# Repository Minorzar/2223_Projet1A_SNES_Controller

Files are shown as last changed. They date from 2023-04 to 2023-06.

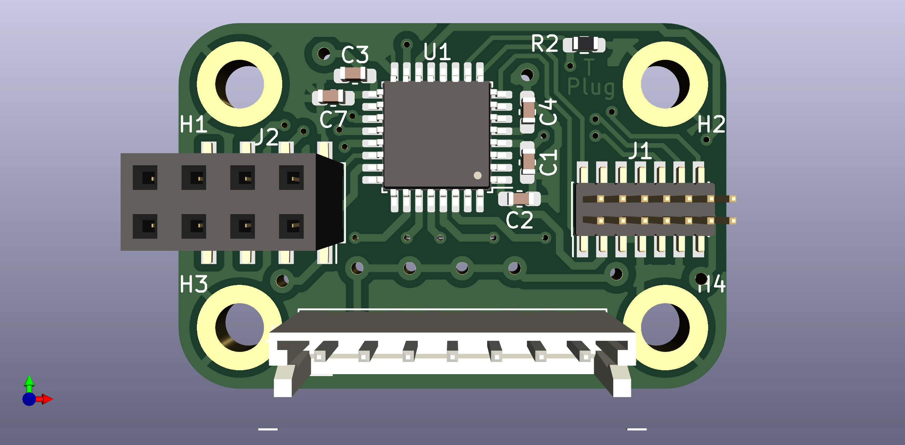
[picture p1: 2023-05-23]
Project_controller/Hardware/Kicad/# Image/Routing_V3_0_d/Plug_NRF24L01_Exclude_V3-3_3D_Top.png

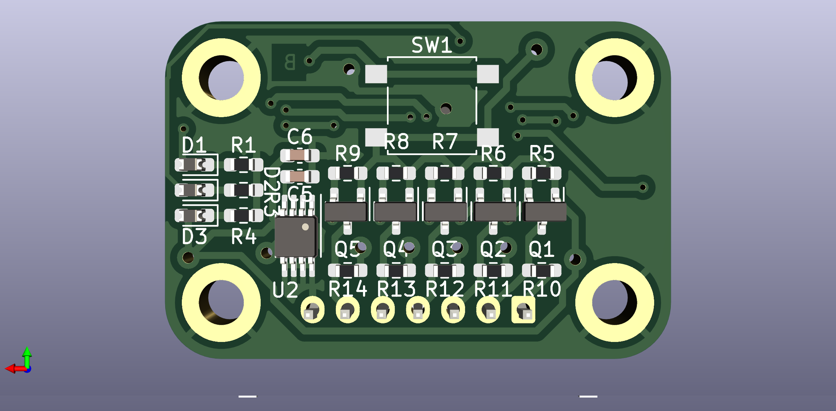
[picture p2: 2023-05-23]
Project_controller/Hardware/Kicad/# Image/Routing_V3_0_d/Plug_NRF24L01_Exclude_V3-4_3D_Bottom.png

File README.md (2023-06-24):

# SNES Project (Controller)

This is the repository of the SNES project carried out at ENSEA by the promotion of 2025.

In the first year, as part of a three-month project, we will attempt to create our own version of the SNES controller. The aim will be to complete the controller ourselves, both in terms of hardware and software, while adding features that were not present on the original controller. However, this is only the first part of our SNES project, as we'll be continuing the project next year, this time focusing on the console itself. As such, this repository will probably only contain files relevant to the controller.

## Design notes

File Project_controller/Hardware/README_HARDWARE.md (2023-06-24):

# SNES Controller (Hardware)

The purpose of this document is to explain the hardware operation of the controller and the reasons behind our choices.

Objective:
- We will attempt to recreate the SNES controller while adding a new feature that is unrelated to the original console. The initial aim of this project was to make a wireless controller for the NES or SNES.

Controller:
- The reason we chose an SNES controller over an NES controller is that, project constraints permitting, we intend to give it the ability to switch between SNES and NES modes using a toggle button. We considered that such a function should be possible, as the communication protocol between the two controllers is quite similar.

Plug:
- In order to make this controller wireless, we need a device that will act as a link between the controller and the console. With this in mind, we've opted for a plug that connects directly to the console. This plug will need a communication module, which will be the NRF24L01. The reason for this choice will be explained below and the operation of the NRF24L01 will be explained in greater detail in the software section of our project.

PCB:
- The main challenge of our project will be to design a PCB. To do this, we'll be using KiCad software. Knowing that we'll be creating a controller and a plug, we've estimated that we'll need exactly two PCBs, one for each.

Microprocessor:
- A microprocessor will be required on both the plug and the controller. Their main role will be to receive data from the controller, which will be transmitted via the NRF24L01 communication protocol to the plug, and then adapt it to the console using the SNES communication protocol.
- We chose to use an STM32-LK412KBTx for the plug and controller, as it was the most readily available while having sufficient GPIOs and being the smallest.

NRF24L01:
- We decided to use the NRF24 for two reasons. The first is its low power consumption, as it costs less than many other communication devices. The secnd is its low latency compared with other available options.
- To use the NRF24L01 module, we decided to create two types of PCB: "Include" in which the NRF24L01 is directly included on the PCB, and "Exclude" in which the NRF24L01 will be excluded and will have to be connected to our PCB. The reason we decided on these two PCB types was to provide insurance in case the included version didn't work properly. Unfortunately, it really did happened and we had to abandon the included version, although not for the reasons we expected. It was mainly due to problems with KiCad and the antenna required for the NRF24L01. As a result, we had to fall back on the excluded version.

## Controller

The initial controller design was to include 15 buttons, a few LEDs, a power supply with DC/DC converter and the various parts required for the NRF24L01.

Buttons:
- To reproduce the behavior of an SNES controller, we'll need at least 12 buttons, to which we'll add the pairing, power and SNES/NES mode buttons.
- [4] Directional cross (Up/Down/Left/Right)
- [6] Push buttons (A/B/X/Y/Start/Select)
- [2] Bumper buttons (L/R)
- [1] Pairing button
- [1] On/Off switch
- [1] SNES/NES mode switch

LEDs:
- To make sure our controller and plug are working properly, we've added LEDs to indicate whether certain parts are working or not. Here, we were mainly concerned with the controller's power supply.

Power supply:
- As the controller will be wireless, it will need to be powered by a power source. The most obvious solution was to use some kind of battery. We chose to use a 4.3V lithium-ion battery to compensate for the voltage drop on some parts of the controller, as most components operate on 3.3V.

DC/DC converter:
- To convert the voltage from 4.3V to 3.3V, we used a DC/DC converter. We first considered using an AMS1117 linear voltage regulator, but as it was not available, we decided to replace it with a MIC5219-3.3YMM.

## Plug

The purpose of our plug is to act as a data bridge between the controller and the console. As the console is powered by a 5V voltage, we'll need to lower it to 3.3V to suit our microprocessor. To do this, we'll use level shifters for each of the SNES signals passing through our SNES port, and once again a MIC5219-3.3YMM DC/DC converter for our microprocessor. The PCB will also differ depending on whether the NRF24L01 is included or not.
- If the NRF24L01 is excluded, only one connector needs to be added to the PCB.
- If the NRF24L01 is included, in addition to the NRF24L01 module, we'll also need to add a crystal and antenna.

LEDs:
- Similar with the controller, to make sure the plug is working properly, we've added LEDs to indicate whether certain parts are working or not, in particular the 3.3V, 5.5V voltage source and plug status. The "plug status" has deliberately not been detailed, as it will most likely be used for the various checks that may be carried out during testing.

Crystal / Antenna:
- As the "included" version has been dropped, we won't go into the details of what was used here. The only thing to note is that a certain frequency was required to select our crystal, and that we tried to use the same type of antenna found on the NRF24L01.

## Readme

Main: /README.md
- https://github.com/Minorzar/snes_project_ensea2025/blob/main/README.md

Hardware: /Hardware/README_HARDWARE.md
- https://github.com/Minorzar/snes_project_ensea2025/blob/main/Hardware/README_HARDWARE.md

KiCad: /Hardware/Kicad/README_KICAD.md
- https://github.com/Minorzar/snes_project_ensea2025/blob/main/Hardware/Kicad/README_KICAD.md

Software: /Software/README_SOFTWARE.md
- https://github.com/Minorzar/snes_project_ensea2025/blob/main/Software/README_SOFTWARE.md

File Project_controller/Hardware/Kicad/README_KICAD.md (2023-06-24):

# SNES Controller (KiCad)

The purpose of this document is to explain the operations behind the design of our PCBs made with KiCad.

## Folder Structure

Projects:
- Our KiCad projects consist of a controller and a plug, both of which have two distinct versions: the exclude version and the include version.
    - The exclude version will have a connector which will be used to connect an NRF24L01 to it.
    - The include version will have the NRF24L01 directly on the PCB, along with the crystal and antenna corresponding to the latter's specifications.
- As indicated in the README_HARDWARE, our project consists of 2 PCBs, one for the controller and the other for the plug. We will therefore have 4 KiCad projects with different versions over the course of the projects.

Library:
- The library section contains the libraries used in KiCad for our projects. The files found there mainly concern the use of the NRF24L01 in particular.

Image:
- This folder has no particular function other than practical. It provides quick access to the status of a KiCad project in its latest useful version in the form of images that can be shared and viewed more easily. Here, different versions of the schematic, routing and 3D views can be seen.

Unused:
- The KiCad projects in this folder contain the "Include" versions of our controller and plug, as this was deemed infeasible due to bizarre restrictions with our antenna on the KiCad software. The only references we've found to this problem date back several years, and most of them have not been resolved on community forums and social networks.

## Schematic

Designing the schematics for our PCBs was fairly straightforward, as we had already planned our main components in advance. Since the purposes of our plug and controller are quite similar, namely data transmission, their schematics won't be too different. However, there are still a few notable differences, such as the fact that the controller will have a battery and more buttons; or that our plug will have several level shifters to convert signals into a voltage suitable between our microprocessor and console. More importantly, GPIO Extenders were added to our controller as other constraints were imposed during the project, such as the addition of LEDs to show the current state of our battery. The latter cost us a few too many pins on our microprocessor, and we ended up needing just one extra pin. That being said, after following the datasheets, all that's left to do is place the passive components needed for the IC, LEDs and buttons to work properly. The main components are as follows:

Controller:
- Microprocessor
- SWD connector
- DC/DC converter
- NRF24 connector
- Buttons and switches
- LEDs
- Mounting holes
- Battery connector
- GPIO Extenders

Plug:
- Microprocessor
- SWD connector
- DC/DC converter
- NRF24 connector
- SNES connector
- Buttons and switches
- LEDs
- Mounting holes
- Level shifters

## PCB (Routing)

When routing our PCBs, we had two main concerns: the size of our controller and the use of resources for our plug. As our controller had to meet certain size criteria, we couldn't afford to make it small and use as few resources as possible to make it. Our plug, on the other hand, was exactly the opposite.

Plug:
- To create the smallest possible PCB for our plug, we first grouped together all the more or less interconnected components, such as the SNES port and the level shifters with their resistors. Once this was done, we placed each connector on either side of the PCB, so that when the microprocessor was placed in the center, the connections would be made more or less easily. We also took care to place the decoupling capacitors as close as possible to each IC output voltage, to ensure proper operation. All that remained was to place the LEDs and button in an appropriate location. We also tried to reduce the use of copper by using ground vias, but with a PCB as small as it is, there wasn't much room for improvement.

Controller:
- The design of our controller PCB was based on a totally different mindset from that of the plug. We first had to measure the size of a controller and make sure the PCB met these criteria, as we were going to be soldering our buttons to it. As a rough estimate of the size of our controller, we decided to place the PCB mounting holes according to the following criteria: +/- 10mm horizontally and +/- 20mm vertically for mounting holes on the same side and +125mm between our inner mounting holes on the vertical.
- The directional cross buttons and the A, B, X, Y buttons are each separated by 25 mm horizontally and vertically. The Start and Select buttons have both been placed in the center of the controller, in a position similar to that of the original controller. The L and R buttons are both located on the top of the controller in the form of connectors.The reason why the L and R buttons are not buttons is that they are bumpers that will be placed orthogonally to the controller, and therefore cannot be placed on the PCB.
- All other components have been placed in the appropriate locations, such as the GPIO extenders close to the buttons to which they are connected.

## Updates

Over the course of our projects, we have had numerous iterations of our printed circuit boards, namely 6 plug versions and 3 controllers versions.

Plug:
- The first V0 and V1 versions can be considered as training for the routing of a complete PCB.
- Version V2 was designed to correct a number of problems, such as misplaced decoupling capacitors and optimized routing.
- From version V3 onwards, new constraints were imposed on the PCBs design: 0.5 track width, 1.6 mm via size, 0.8 via hole, almost double that of previous versions. These constraints were imposed because of problems associated with the manufacture of these printed circuits. As we gained more experience in routing our PCB, we tried this time to use the bottom surface to place the components and gain more space.
 - A new V4 version had to be made to make some necessary corrections. In particular, we realized that the previous PCB had pin assignment problems. We also took the opportunity to correct some routings that didn't fully comply with the previous constraints.
- Finally, the final version was the V5. There were no major changes from the previous version, apart from new corrections to the pin arrangements.
 
 Controller:
- Apart from the problems we've already mentioned with the plug, the controller hasn't undergone any other major changes. The only notable changes we've made are that we've changed the hexagonal shape of our PCB to a smoother form more reminiscent of the original SNES controller. 

## Readme

Main: /README.md
- https://github.com/Minorzar/snes_project_ensea2025/blob/main/README.md

Hardware: /Hardware/README_HARDWARE.md
- https://github.com/Minorzar/snes_project_ensea2025/blob/main/Hardware/README_HARDWARE.md

KiCad: /Hardware/Kicad/README_KICAD.md
- https://github.com/Minorzar/snes_project_ensea2025/blob/main/Hardware/Kicad/README_KICAD.md

Software: /Software/README_SOFTWARE.md
- https://github.com/Minorzar/snes_project_ensea2025/blob/main/Software/README_SOFTWARE.md

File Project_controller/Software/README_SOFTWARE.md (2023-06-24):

# SNES Controller (Software)

The purpose of this document is to explain the algorithms and programming elements we've written for the two microprocessors in our project: one for the controller, the other for the plug.

## SNES Communication Protocol

The SNES console communicates with the controller and retrieves data in a specific way. That's why we have to adapt to it and ensure that our microprocessors reproduce these steps correctly.

SNES port features:
- Frequency: 60 Hz / 16.67 ms
- Clock period: 12 μs
- Pin 1: +5 V
- Pin 2: Data_clock
- Pin 3: Data_latch
- Pin 4: Serial_data
- Pin 5: N/A
- Pin 6: N/A
- Pin 7: Ground

Communication sequence:   
- [1] B
- [2] Y
- [3] Select
- [4] Start
- [5] Up
- [6] Down
- [7] Left
- [8] Right
- [9] A
- [10] X
- [11] L
- [12] R
- [13] High
- [14] High
- [15] High
- [16] High
- (17 Low)

Operation:
- Every 16.67 ms, the console sends a 12 μs wide pulse to pin 3, instructing the controller to latch the state of the buttons.
- After 6 μs, the console sends 16 clock cycles to the "Data_clock" pin.
    - On the rising edge, the controller, or our plug in particular for this project, serially shifts the states of the buttons locked on the "Serial_data" pin.
    - On the falling edge, the CPU inside the SNES samples the data.

Algorithm:
- In order to comply with the above-mentioned protocol, the plug's microprocessor must be able to detect the various signals sent by the console and respond accordingly.
    - If no latch command is given, the button states are regularly updated.
    - If the latch command is given, the button states are no more updated and are sent one by one after each rising edge of the clock.
    - When this is complete, the microprocessor resumes updating the button states.

## Battery

- One of the most important functions of a wireless controller is to display its battery charge, as we wouldn't want it to unexpectedly run out of power. The easiest way to do this is to measure the battery voltage. A fully charged battery will have a high voltage, and then slowly decrease as it is used. Fortunately, our microprocessor has an analog pin that allows us to do just that.
- Once this value has been obtained, it must be converted to an integer between 1 and 12. The reason for these precise numbers is that we have exactly 12 LEDs to represent the current state of the battery.

## I2C Devices

- To make our controller, we had planned to use a set amount of digital inputs and outputs. However, as the projects progressed and new constraints were added, we ended up not having enough GPIOs to achieve all of our goals. As a result, we’ve used 2 GPIO Extenders and 1 LED Driver.
- These two devices communicate with the microprocessor via a protocol called I2C, which allows multiple modules to be connected to the same lines. The functions required to use the I2C protocol are provided by STM32CubeIDE; all you need to do is specify the device address and the payload to send or receive data.
    - GPIO Extenders are fairly easy to use, as you simply need to call the receive command at the right address to obtain the data byte in return.
    - However, the LED driver ended up more complex than the latter. It can control the light intensity of our 16 different LEDs. To use it, the microprocessor must send 2 payload bytes using the I2C protocol: the first corresponding to the register number and the second to the register value. As we only wanted the LEDs to be on or off, we created a function to modify the register of each LED so that this was the case.

## NRF24 (Wireless Communication)

As we explained in the "Hardware" section, as part of our project specifications, we needed the controller to be able to operate wirelessly. That's why we needed to be able to couple both our controller and the plug in order to receive the player's inputs.

NRF24 characteristics:
- Frequency: 2,4GHz
- Range: approx. 200m
- Maximum data flow: 2Mb/s (which is certainly much more than we'll need)

Communication between the microprocessor and the communication device:
- The operation of the NRF24 module is quite complex in itself. A series of specific actions must be performed so that it can trigger various commands such as receiving or sending data. Thanks to several of its commands, we can also read and write to the module's registers.
- The main problem will be that all of our command will have to be done through our microprocessor. This means that we will have to use another communication protocol in order to use the NRF24: the SPI protocol. Fortunately, the functions necessary to SPI communication are already provided in STM32CubeIDE, but it doesn’t change the fact that the whole process can be quite tedious.
- The main problem will be that all our commands will have to be made via our microprocessor. This means we'll have to use another communication protocol to operate the NRF24: the SPI protocol. Fortunately, the functions required for SPI communication are already provided in STM32CubeIDE, but this doesn't change the fact that the whole process can be quite tedious.
- To make the NRF24 work, we still had to write a whole library of functions. However, despite our best efforts, we couldn't get it to work, so we decided to look at other libraries that had been written by other people. In the end, we still had problems, but we did manage to transmit data between two NRF24s, although not as reliably as we'd hoped. On the other hand, we still don't know whether our first program worked or not, as it seems that our test equipment was one of the causes of its failure.

Data transmission:
- Once the library has been set up, its use can be considered fairly straightforward.
- First of all, the microprocessor needs to retrieve the controller data from inside the 2 GPIO Extenders (1 byte of data each). 
- It then sends them to the NRF24 module for wireless transmission to the plug module.
- After the data has been received on the plug module, it is sent to the CPU.
- This data is then converted into 16 bits of information corresponding to the states of our buttons.
- Finally, they are transmitted to the console according to the communication protocol.

## Readme

Main: /README.md
- https://github.com/Minorzar/snes_project_ensea2025/blob/main/README.md

Hardware: /Hardware/README_HARDWARE.md
- https://github.com/Minorzar/snes_project_ensea2025/blob/main/Hardware/README_HARDWARE.md

KiCad: /Hardware/Kicad/README_KICAD.md
- https://github.com/Minorzar/snes_project_ensea2025/blob/main/Hardware/Kicad/README_KICAD.md

Software: /Software/README_SOFTWARE.md
- https://github.com/Minorzar/snes_project_ensea2025/blob/main/Software/README_SOFTWARE.md

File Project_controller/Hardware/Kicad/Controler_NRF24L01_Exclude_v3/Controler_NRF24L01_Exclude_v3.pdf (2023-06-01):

Controler_NRF24L01_Exclude_v3

Page 1

Component Count: | 87
Item | Qty | Reference(s) | Value | Footprint
1 | 1 C1 | 22uF | Capacitor_SMD:CP_Elec_5x5.4
2 | 1 C2 | 1nF | Capacitor_SMD:C_0603_1608Metric_Pad1.08x0.95mm_HandSolder
3 | 2 C3, C5 | 100n | Capacitor_SMD:C_0603_1608Metric_Pad1.08x0.95mm_HandSolder
4 | 1 C4 | 1u | Capacitor_SMD:C_0603_1608Metric_Pad1.08x0.95mm_HandSolder
5 | 1 C6 | 10u | Capacitor_SMD:C_0603_1608Metric_Pad1.08x0.95mm_HandSolder
6 | 3 C7, C8, C10 | 100nF | Capacitor_SMD:C_0603_1608Metric_Pad1.08x0.95mm_HandSolder
7 | 1 C9 | 470p | Capacitor_SMD:C_0603_1608Metric_Pad1.08x0.95mm_HandSolder
8 | 1 D2 | LED_Small | LED_SMD:LED_0603_1608Metric_Pad1.05x0.95mm_HandSolder
9 | 1 D3 | G1 | LED_SMD:LED_0603_1608Metric_Pad1.05x0.95mm_HandSolder
10 | 1 D4 | G2 | LED_SMD:LED_0603_1608Metric_Pad1.05x0.95mm_HandSolder
11 | 1 D5 | G3 | LED_SMD:LED_0603_1608Metric_Pad1.05x0.95mm_HandSolder
12 | 1 D6 | G4 | LED_SMD:LED_0603_1608Metric_Pad1.05x0.95mm_HandSolder
13 | 1 D7 | G5 | LED_SMD:LED_0603_1608Metric_Pad1.05x0.95mm_HandSolder
14 | 1 D8 | G6 | LED_SMD:LED_0603_1608Metric_Pad1.05x0.95mm_HandSolder
15 | 1 D9 | G7 | LED_SMD:LED_0603_1608Metric_Pad1.05x0.95mm_HandSolder
16 | 1 D10 | G8 | LED_SMD:LED_0603_1608Metric_Pad1.05x0.95mm_HandSolder
17 | 1 D11 | O1 | LED_SMD:LED_0603_1608Metric_Pad1.05x0.95mm_HandSolder
18 | 1 D12 | O2 | LED_SMD:LED_0603_1608Metric_Pad1.05x0.95mm_HandSolder
19 | 1 D13 | O3 | LED_SMD:LED_0603_1608Metric_Pad1.05x0.95mm_HandSolder
20 | 1 D14 | O4 | LED_SMD:LED_0603_1608Metric_Pad1.05x0.95mm_HandSolder
21 | 1 D15 | R1 | LED_SMD:LED_0603_1608Metric_Pad1.05x0.95mm_HandSolder
22 | 1 D16 | R2 | LED_SMD:LED_0603_1608Metric_Pad1.05x0.95mm_HandSolder
23 | 1 D17 | R3 | LED_SMD:LED_0603_1608Metric_Pad1.05x0.95mm_HandSolder
24 | 1 D18 | R4 | LED_SMD:LED_0603_1608Metric_Pad1.05x0.95mm_HandSolder
25 | 6 H1, H2, H3, H4, H5, H6 | MountingHole_Pad | MountingHole:MountingHole_3.2mm_M3_DIN965_Pad
26 | 1 J1 | Conn_01x02 | Connector_JST:JST_XH_B2B-XH-A_1x02_P2.50mm_Vertical
27 | 1 J2 | Conn_02x07_Odd_Even Connector_PinHeader_1.27mm:PinHeader_2x07_P1.27mm_Vertical_SMD
28 | 2 J3, J4 | Conn_01x03 | Connector_JST:JST_XH_B3B-XH-A_1x03_P2.50mm_Vertical
29 | 20 R1, R2, R3, R13, R18, R20, R21, R22, R23, R24, R25, R26, R27, R28, R29, R30, R31, R32, R33, R34 | 1K | Resistor_SMD:R_0603_1608Metric_Pad0.98x0.95mm_HandSolder
30 | 2 R4, R7 | 1k | Resistor_SMD:R_0603_1608Metric_Pad0.98x0.95mm_HandSolder
31 | 7 R5, R6, R8, R11, R12, R14, R16 | 10K | Resistor_SMD:R_0603_1608Metric_Pad0.98x0.95mm_HandSolder
32 | 2 R9, R10 | 1M | Resistor_SMD:R_0603_1608Metric_Pad0.98x0.95mm_HandSolder
33 | 2 SW1, SW10 | SW_DIP_x01 | Button_Switch_SMD:SW_DIP_SPSTx01_Slide_Copal_CHS-01B_W7.62mm_P1.27mm
34 | 10 SW2, SW3, SW4, SW5, SW6, SW8, SW9, SW11, SW12, SW13 | SW_Push | Button_Switch_SMD:SW_SPST_B3S-1000
35 | 1 SW7 | SW_SPST | Button_Switch_SMD:SW_SPST_B3S-1000
36 | 1 U1 | STM32L412KBTx | Package_QFP:LQFP-32_7x7mm_P0.8mm
37 | 1 U2 | nRF24_Full | Connector_PinHeader_2.54mm:PinHeader_2x04_P2.54mm_Vertical
38 | 1 U3 | MIC5219-3.3YMM | Package_SO:MSOP-8_3x3mm_P0.65mm
39 | 1 U4 | PCA9685PW | Package_SO:TSSOP-28_4.4x9.7mm_P0.65mm
40 | 2 U5, U6 | PCF8574TS | Package_SO:SSOP-20_4.4x6.5mm_P0.65mm

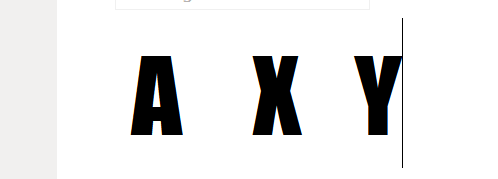
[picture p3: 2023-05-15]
Project_controller/Hardware/Shell/Controller_Shell/LETTER.PNG

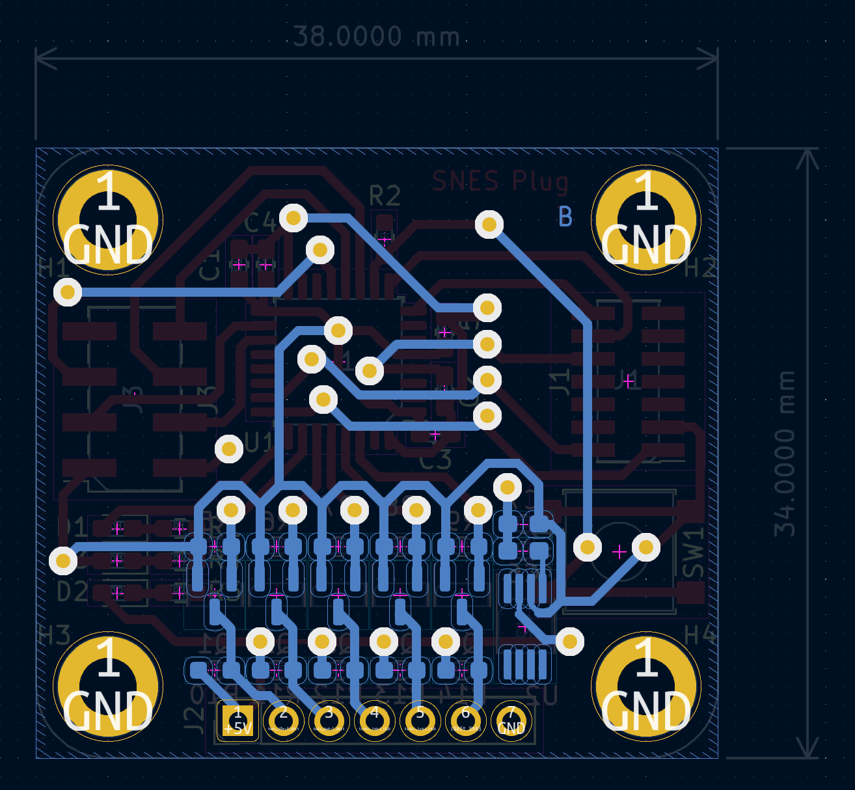
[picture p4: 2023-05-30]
Project_controller/Hardware/Kicad/# Image/Routing_V4_0_a/Plug_NRF24L01_Exclude_V4_0_a-4_PCB_Bot.png

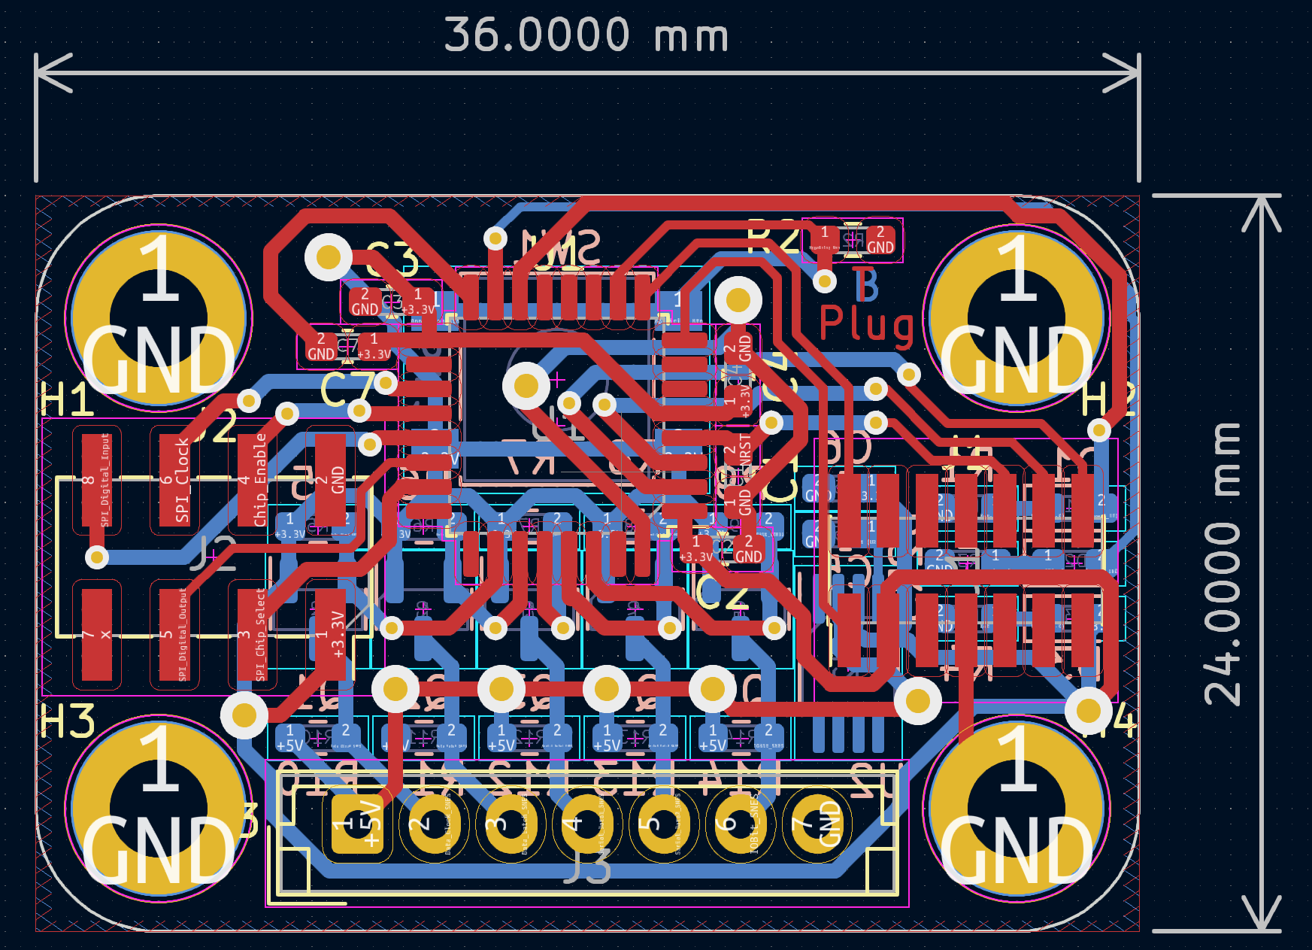
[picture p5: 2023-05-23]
Project_controller/Hardware/Kicad/# Image/Routing_V3_0_d/Plug_NRF24L01_Exclude_V3-2_PCB.png

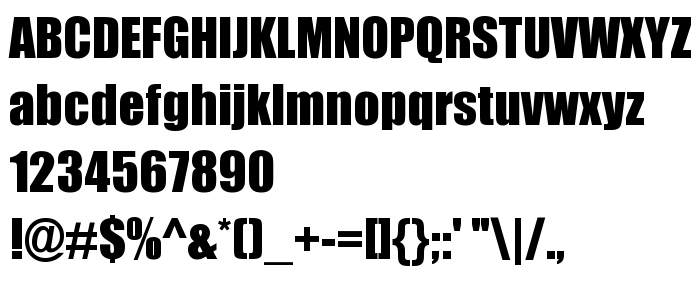
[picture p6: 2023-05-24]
Project_controller/Hardware/Shell/Controller_Shell/abc-6890_c0027cf4199c69556187607327351ea6.png

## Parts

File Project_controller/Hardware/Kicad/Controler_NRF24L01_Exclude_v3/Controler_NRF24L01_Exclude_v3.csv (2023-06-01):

Source: | /home/nicolas/git/Student_Projects/2223_Projet1AB/snes_project_ensea2025/Hardware/Kicad/Controler_NRF24L01_Exclude_v3/Controler_NRF24L01_Exclude_v3.kicad_sch
Date: | mer. 31 mai 2023 16:56:17
Tool: | Eeschema 7.0.2-6a45011f42~172~ubuntu22.04.1
Generator: | /usr/share/kicad/plugins/bom_csv_grouped_by_value.py
Component Count: | 87
Collated Components:
Item | Qty | Reference(s) | Value | LibPart | Footprint | Datasheet | DNP
1 | 1 | C1 | 22uF | Device:C_Polarized | Capacitor_SMD:CP_Elec_5x5.4 | ~
2 | 1 | C2 | 1nF | Device:C_Small | Capacitor_SMD:C_0603_1608Metric_Pad1.08x0.95mm_HandSolder | ~
3 | 2 | C3, C5 | 100n | Device:C_Small | Capacitor_SMD:C_0603_1608Metric_Pad1.08x0.95mm_HandSolder | ~
4 | 1 | C4 | 1u | Device:C_Small | Capacitor_SMD:C_0603_1608Metric_Pad1.08x0.95mm_HandSolder | ~
5 | 1 | C6 | 10u | Device:C_Small | Capacitor_SMD:C_0603_1608Metric_Pad1.08x0.95mm_HandSolder | ~
6 | 3 | C7, C8, C10 | 100nF | Device:C_Small | Capacitor_SMD:C_0603_1608Metric_Pad1.08x0.95mm_HandSolder | ~
7 | 1 | C9 | 470p | Device:C_Small | Capacitor_SMD:C_0603_1608Metric_Pad1.08x0.95mm_HandSolder | ~
8 | 1 | D2 | LED_Small | Device:LED_Small | LED_SMD:LED_0603_1608Metric_Pad1.05x0.95mm_HandSolder | ~
9 | 1 | D3 | G1 | Device:LED | LED_SMD:LED_0603_1608Metric_Pad1.05x0.95mm_HandSolder | ~
10 | 1 | D4 | G2 | Device:LED | LED_SMD:LED_0603_1608Metric_Pad1.05x0.95mm_HandSolder | ~
11 | 1 | D5 | G3 | Device:LED | LED_SMD:LED_0603_1608Metric_Pad1.05x0.95mm_HandSolder | ~
12 | 1 | D6 | G4 | Device:LED | LED_SMD:LED_0603_1608Metric_Pad1.05x0.95mm_HandSolder | ~
13 | 1 | D7 | G5 | Device:LED | LED_SMD:LED_0603_1608Metric_Pad1.05x0.95mm_HandSolder | ~
14 | 1 | D8 | G6 | Device:LED | LED_SMD:LED_0603_1608Metric_Pad1.05x0.95mm_HandSolder | ~
15 | 1 | D9 | G7 | Device:LED | LED_SMD:LED_0603_1608Metric_Pad1.05x0.95mm_HandSolder | ~
16 | 1 | D10 | G8 | Device:LED | LED_SMD:LED_0603_1608Metric_Pad1.05x0.95mm_HandSolder | ~
17 | 1 | D11 | O1 | Device:LED | LED_SMD:LED_0603_1608Metric_Pad1.05x0.95mm_HandSolder | ~
18 | 1 | D12 | O2 | Device:LED | LED_SMD:LED_0603_1608Metric_Pad1.05x0.95mm_HandSolder | ~
19 | 1 | D13 | O3 | Device:LED | LED_SMD:LED_0603_1608Metric_Pad1.05x0.95mm_HandSolder | ~
20 | 1 | D14 | O4 | Device:LED | LED_SMD:LED_0603_1608Metric_Pad1.05x0.95mm_HandSolder | ~
21 | 1 | D15 | R1 | Device:LED | LED_SMD:LED_0603_1608Metric_Pad1.05x0.95mm_HandSolder | ~
22 | 1 | D16 | R2 | Device:LED | LED_SMD:LED_0603_1608Metric_Pad1.05x0.95mm_HandSolder | ~
23 | 1 | D17 | R3 | Device:LED | LED_SMD:LED_0603_1608Metric_Pad1.05x0.95mm_HandSolder | ~
24 | 1 | D18 | R4 | Device:LED | LED_SMD:LED_0603_1608Metric_Pad1.05x0.95mm_HandSolder | ~
25 | 6 | H1, H2, H3, H4, H5, H6 | MountingHole_Pad | Mechanical:MountingHole_Pad | MountingHole:MountingHole_3.2mm_M3_DIN965_Pad | ~
26 | 1 | J1 | Conn_01x02 | Connector_Generic:Conn_01x02 | Connector_JST:JST_XH_B2B-XH-A_1x02_P2.50mm_Vertical | ~
27 | 1 | J2 | Conn_02x07_Odd_Even | Connector_Generic:Conn_02x07_Odd_Even | Connector_PinHeader_1.27mm:PinHeader_2x07_P1.27mm_Vertical_SMD | ~
28 | 2 | J3, J4 | Conn_01x03 | Connector_Generic:Conn_01x03 | Connector_JST:JST_XH_B3B-XH-A_1x03_P2.50mm_Vertical | ~
29 | 20 | R1, R2, R3, R13, R18, R20, R21, R22, R23, R24, R25, R26, R27, R28, R29, R30, R31, R32, R33, R34 | 1K | Device:R_Small | Resistor_SMD:R_0603_1608Metric_Pad0.98x0.95mm_HandSolder | ~
30 | 2 | R4, R7 | 1k | Device:R_Small | Resistor_SMD:R_0603_1608Metric_Pad0.98x0.95mm_HandSolder | ~
31 | 7 | R5, R6, R8, R11, R12, R14, R16 | 10K | Device:R_Small | Resistor_SMD:R_0603_1608Metric_Pad0.98x0.95mm_HandSolder | ~
32 | 2 | R9, R10 | 1M | Device:R_Small | Resistor_SMD:R_0603_1608Metric_Pad0.98x0.95mm_HandSolder | ~
33 | 2 | SW1, SW10 | SW_DIP_x01 | Switch:SW_DIP_x01 | Button_Switch_SMD:SW_DIP_SPSTx01_Slide_Copal_CHS-01B_W7.62mm_P1.27mm | ~
34 | 10 | SW2, SW3, SW4, SW5, SW6, SW8, SW9, SW11, SW12, SW13 | SW_Push | Switch:SW_Push | Button_Switch_SMD:SW_SPST_B3S-1000 | ~
35 | 1 | SW7 | SW_SPST | Switch:SW_SPST | Button_Switch_SMD:SW_SPST_B3S-1000 | ~
36 | 1 | U1 | STM32L412KBTx | MCU_ST_STM32L4:STM32L412KBTx | Package_QFP:LQFP-32_7x7mm_P0.8mm | https://www.st.com/resource/en/datasheet/stm32l412kb.pdf
37 | 1 | U2 | nRF24_Full | Antenna_nRF24_2_4GHz:nRF24_FULL | Connector_PinHeader_2.54mm:PinHeader_2x04_P2.54mm_Vertical
38 | 1 | U3 | MIC5219-3.3YMM | Regulator_Linear:MIC5219-3.3YMM | Package_SO:MSOP-8_3x3mm_P0.65mm | http://ww1.microchip.com/downloads/en/DeviceDoc/MIC5219-500mA-Peak-Output-LDO-Regulator-DS20006021A.pdf
39 | 1 | U4 | PCA9685PW | Driver_LED:PCA9685PW | Package_SO:TSSOP-28_4.4x9.7mm_P0.65mm | http://www.nxp.com/documents/data_sheet/PCA9685.pdf
40 | 2 | U5, U6 | PCF8574TS | Interface_Expansion:PCF8574TS | Package_SO:SSOP-20_4.4x6.5mm_P0.65mm | http://www.nxp.com/documents/data_sheet/PCF8574_PCF8574A.pdf

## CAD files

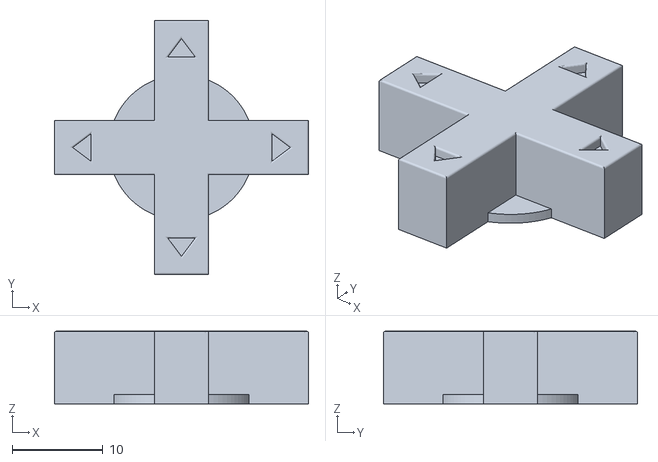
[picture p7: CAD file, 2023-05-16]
Project_controller/Hardware/Shell/Controller_Shell/orignal/Cross v2.stl
28.0 x 28.0 x 8.00

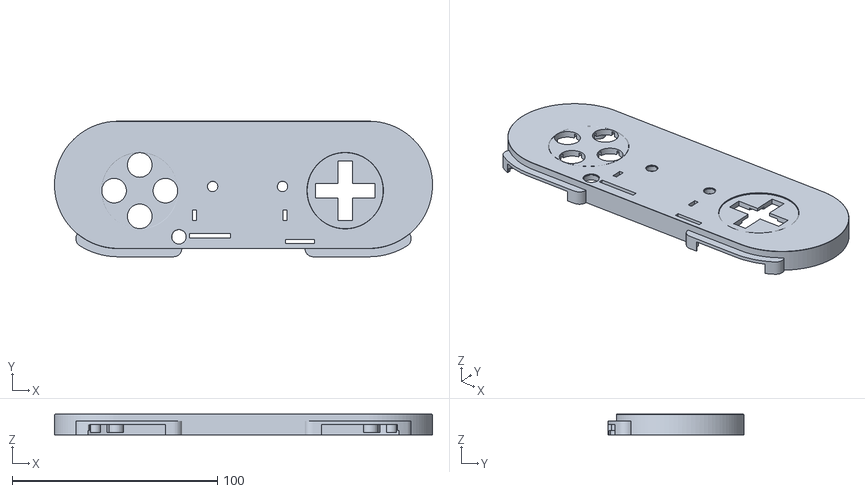
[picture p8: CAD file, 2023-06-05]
Project_controller/Hardware/Shell/Controller_Shell/V3/Haut de la manette v47.stl
184.0 x 66.0 x 10.0

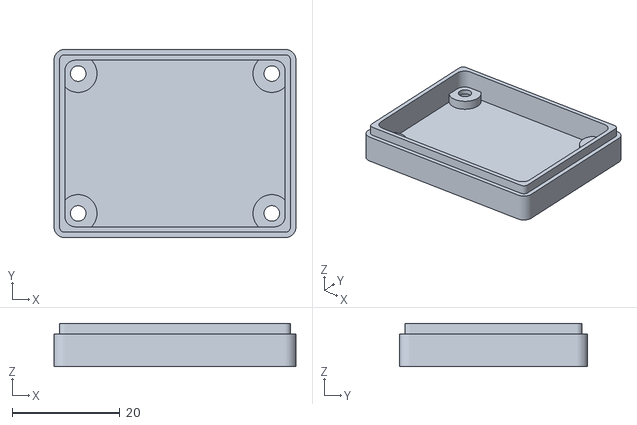
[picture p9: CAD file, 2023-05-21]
Project_controller/Hardware/Shell/Plug_Shell/Base plug v2.stl
45.0 x 35.0 x 8.00

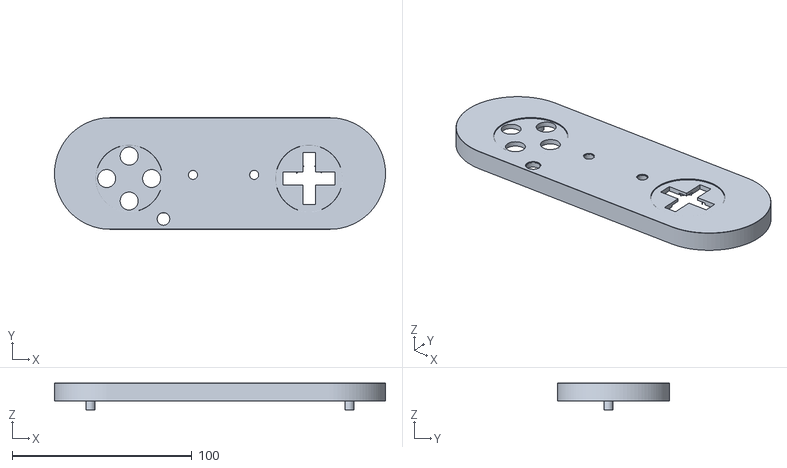
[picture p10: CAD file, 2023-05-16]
Project_controller/Hardware/Shell/Controller_Shell/orignal/Haut de la manette v5.stl
184.0 x 62.0 x 15.0

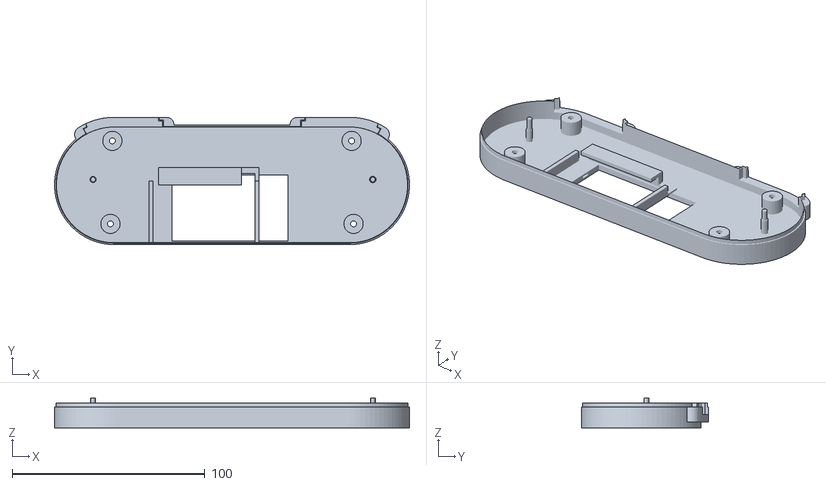
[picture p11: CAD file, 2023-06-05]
Project_controller/Hardware/Shell/Controller_Shell/V3/Base de la manette v9.stl
184.0 x 66.0 x 15.4

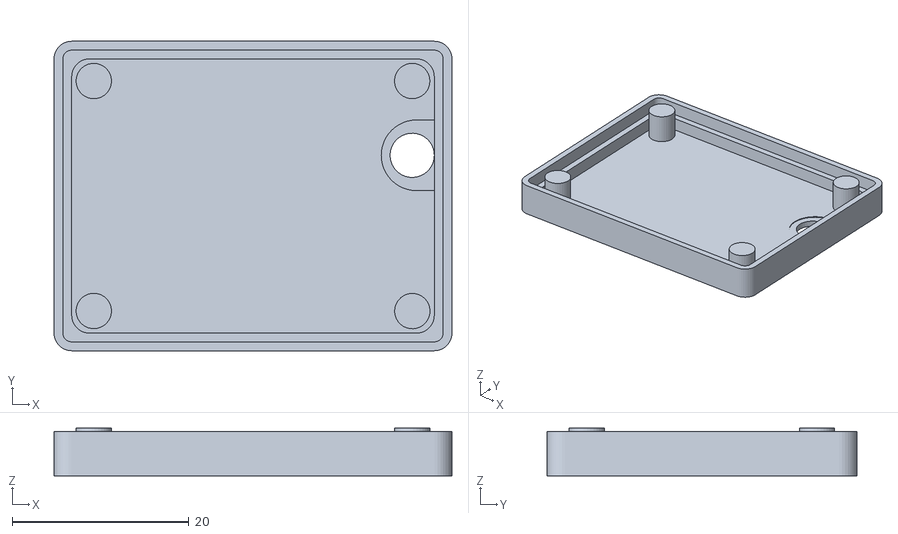
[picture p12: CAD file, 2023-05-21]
Project_controller/Hardware/Shell/Plug_Shell/Haut plug v4.stl
45.0 x 35.0 x 5.40

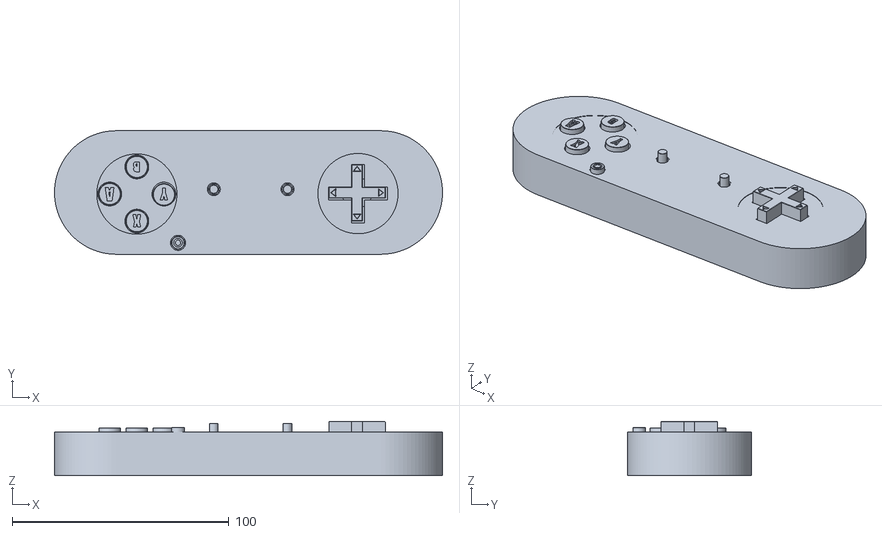
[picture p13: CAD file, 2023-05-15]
Project_controller/Hardware/Shell/Controller_Shell/orignal/MEGA-CONTROLER-ZORD.stl
179.0 x 57.0 x 25.0

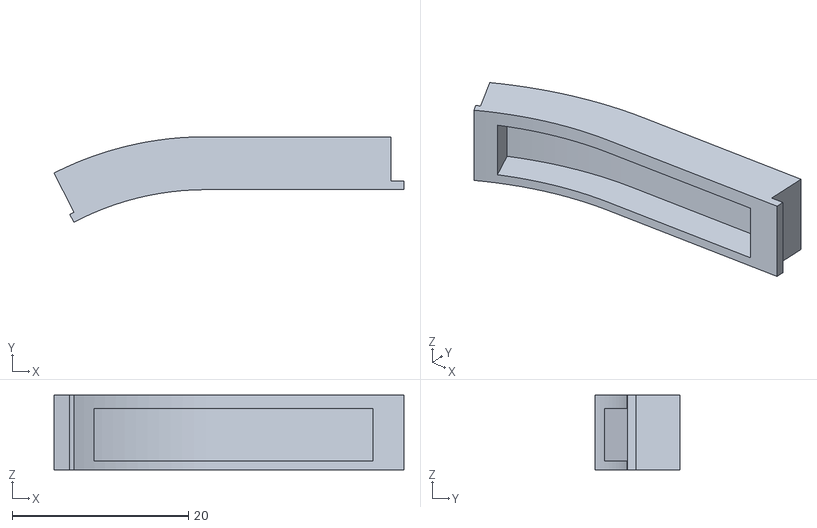
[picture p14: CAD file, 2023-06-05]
Project_controller/Hardware/Shell/Controller_Shell/V3/L button v4.stl
39.7 x 9.69 x 8.50

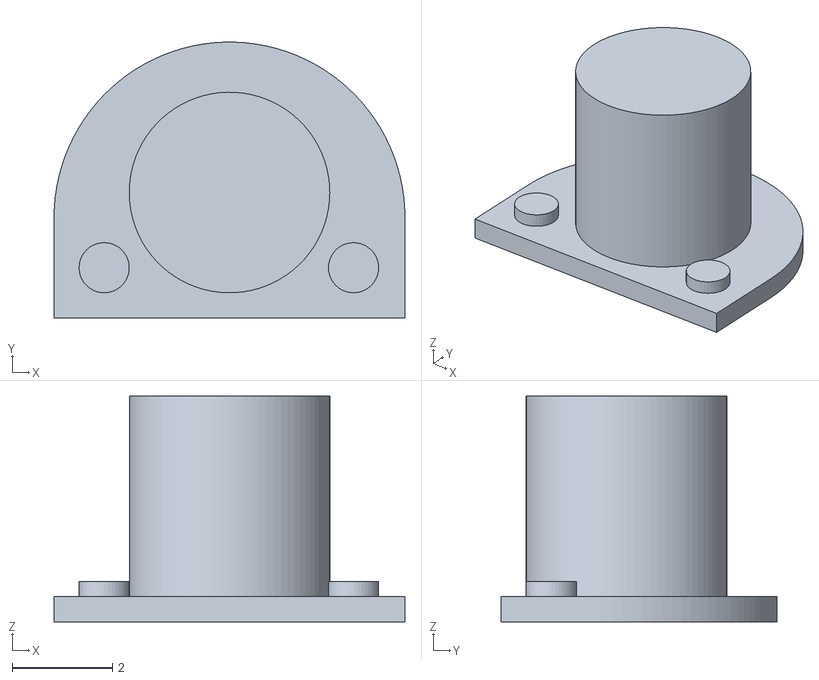
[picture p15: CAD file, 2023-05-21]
Project_controller/Hardware/Shell/Plug_Shell/button v2.stl
7.00 x 5.50 x 4.50

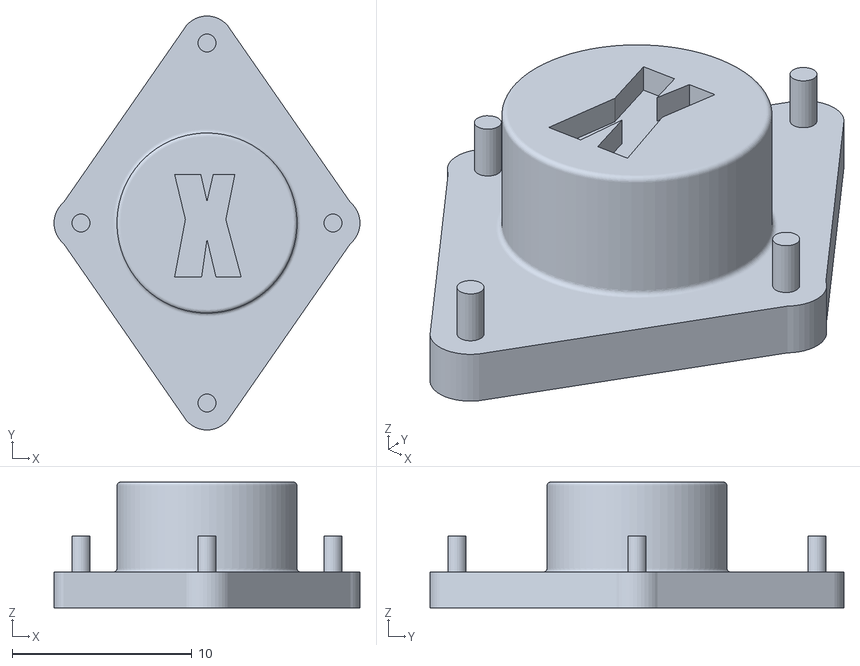
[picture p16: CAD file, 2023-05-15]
Project_controller/Hardware/Shell/Controller_Shell/orignal/Button X v2.stl
17.0 x 23.0 x 7.00

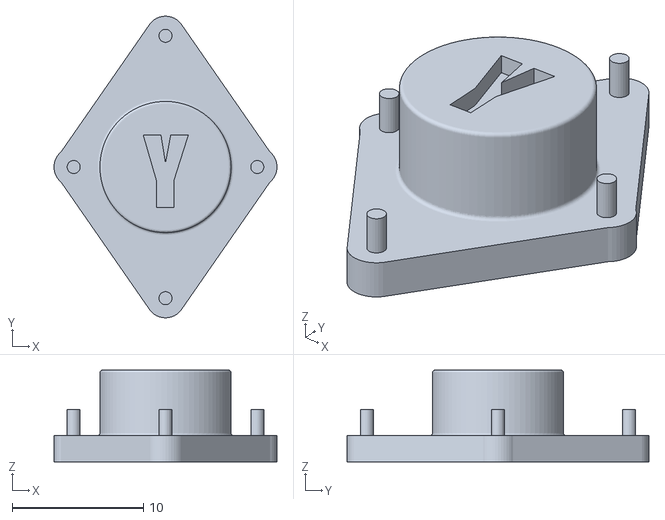
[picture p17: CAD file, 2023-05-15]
Project_controller/Hardware/Shell/Controller_Shell/orignal/Button Y.stl
17.0 x 23.0 x 7.00

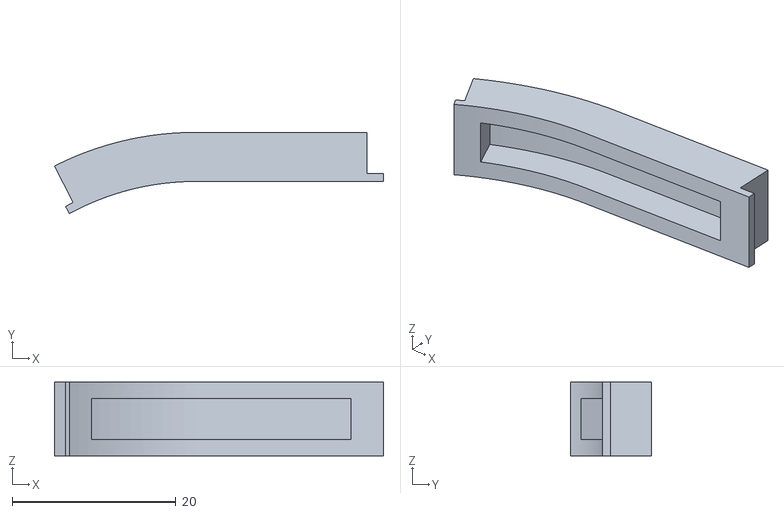
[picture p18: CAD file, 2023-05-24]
Project_controller/Hardware/Shell/Controller_Shell/V3/R button v3.stl
40.2 x 9.93 x 9.00

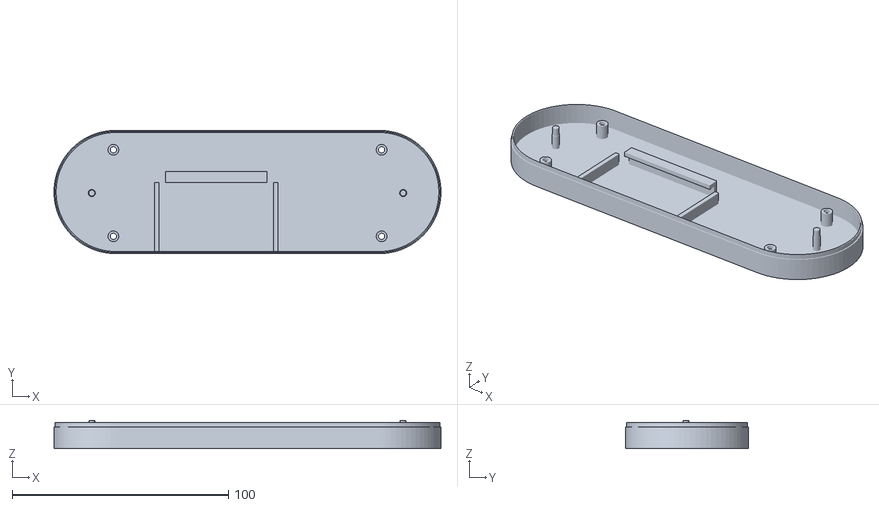
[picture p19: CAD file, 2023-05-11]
Project_controller/Hardware/Shell/Controller_Shell/orignal/Base de la manette v22.stl
178.9 x 57.0 x 13.0

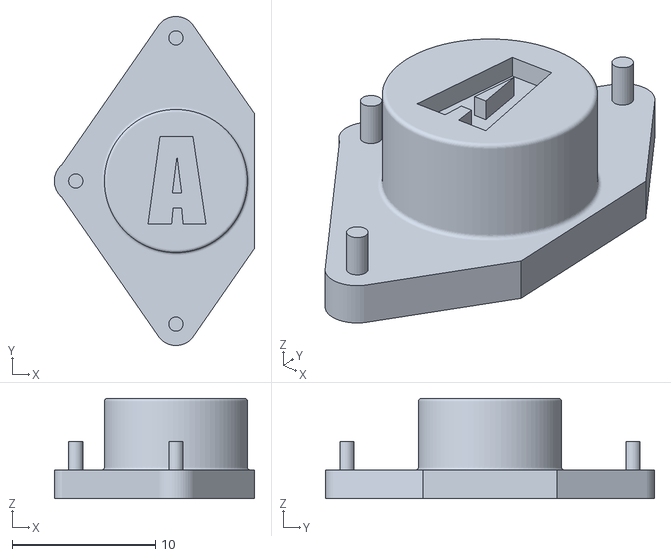
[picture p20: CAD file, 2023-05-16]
Project_controller/Hardware/Shell/Controller_Shell/V3/Button A v2.stl
14.0 x 23.0 x 7.00

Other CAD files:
Project_controller/Hardware/Shell/Controller_Shell/orignal/Button A v1.stl
Project_controller/Hardware/Shell/Controller_Shell/V3/cache v3.stl
Project_controller/Hardware/Shell/Controller_Shell/orignal/button start select.stl
Project_controller/Hardware/Shell/Controller_Shell/V2/Base de la manette v26.stl
Project_controller/Hardware/Shell/Controller_Shell/V2/Button B v1.stl
Project_controller/Hardware/Shell/Controller_Shell/V2/Button X v3.stl
Project_controller/Hardware/Shell/Controller_Shell/V2/Button connection v2.stl
Project_controller/Hardware/Shell/Controller_Shell/V2/Haut de la manette v5.stl
Project_controller/Hardware/Shell/Controller_Shell/V2/button start select.stl
Project_controller/Hardware/Shell/Controller_Shell/V2/cache v3.stl
Project_controller/Hardware/Shell/Controller_Shell/V3/Button B v1.stl
Project_controller/Hardware/Shell/Controller_Shell/V3/Button X v3.stl
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

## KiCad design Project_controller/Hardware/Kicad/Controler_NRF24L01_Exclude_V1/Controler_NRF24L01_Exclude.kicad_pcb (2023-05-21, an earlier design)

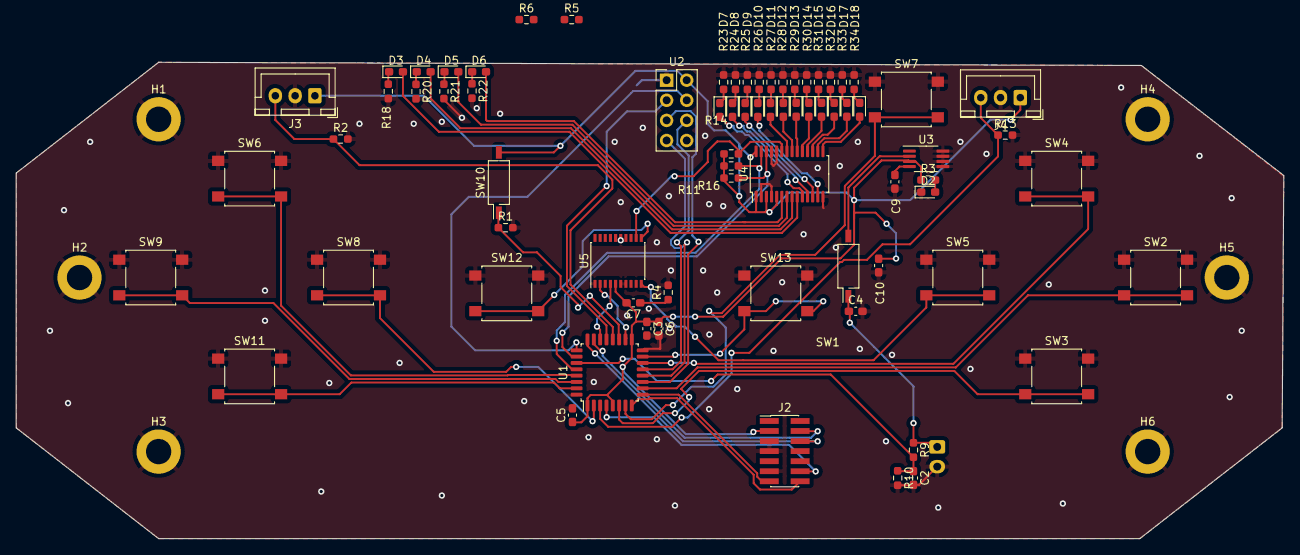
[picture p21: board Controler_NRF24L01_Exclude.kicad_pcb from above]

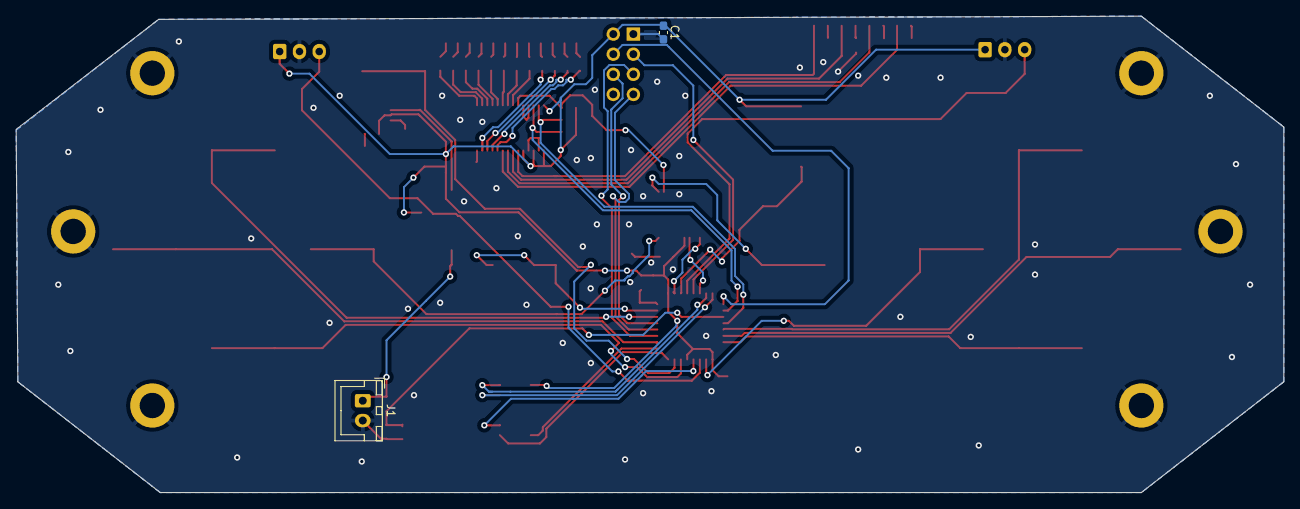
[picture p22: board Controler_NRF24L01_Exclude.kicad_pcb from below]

Board: 2 copper layers, 160.2 x 60.2 mm, 82 parts (2 on the bottom side), 69 nets.

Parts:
C1: 100uF; C_0603_1608Metric_Pad1.08x0.95mm_HandSolder
C2: 1nF; C_0603_1608Metric_Pad1.08x0.95mm_HandSolder
C3, C5: 100n; C_0603_1608Metric_Pad1.08x0.95mm_HandSolder
C4: 1u; C_0603_1608Metric_Pad1.08x0.95mm_HandSolder
C6: 10u; C_0603_1608Metric_Pad1.08x0.95mm_HandSolder
C7: 100µF; C_0603_1608Metric_Pad1.08x0.95mm_HandSolder
C9: 470p; C_0603_1608Metric_Pad1.08x0.95mm_HandSolder
C10: 100nF; C_0603_1608Metric_Pad1.08x0.95mm_HandSolder
D2: LED_Small; LED_0603_1608Metric_Pad1.05x0.95mm_HandSolder
D3: G1; LED_0603_1608Metric_Pad1.05x0.95mm_HandSolder
D4: G2; LED_0603_1608Metric_Pad1.05x0.95mm_HandSolder
D5: G3; LED_0603_1608Metric_Pad1.05x0.95mm_HandSolder
D6: G4; LED_0603_1608Metric_Pad1.05x0.95mm_HandSolder
D7: G5; LED_0603_1608Metric_Pad1.05x0.95mm_HandSolder
D8: G6; LED_0603_1608Metric_Pad1.05x0.95mm_HandSolder
D9: G7; LED_0603_1608Metric_Pad1.05x0.95mm_HandSolder
D10: G8; LED_0603_1608Metric_Pad1.05x0.95mm_HandSolder
D11: O1; LED_0603_1608Metric_Pad1.05x0.95mm_HandSolder
D12: O2; LED_0603_1608Metric_Pad1.05x0.95mm_HandSolder
D13: O3; LED_0603_1608Metric_Pad1.05x0.95mm_HandSolder
D14: O4; LED_0603_1608Metric_Pad1.05x0.95mm_HandSolder
D15: R1; LED_0603_1608Metric_Pad1.05x0.95mm_HandSolder
D16: R2; LED_0603_1608Metric_Pad1.05x0.95mm_HandSolder
D17: R3; LED_0603_1608Metric_Pad1.05x0.95mm_HandSolder
D18: R4; LED_0603_1608Metric_Pad1.05x0.95mm_HandSolder
H1, H2, H3, H4, H5, H6: MountingHole_Pad; MountingHole_3.2mm_M3_DIN965_Pad
J1: Conn_01x02; JST_XH_B2B-XH-A_1x02_P2.50mm_Vertical
J2: Conn_02x07_Odd_Even; PinHeader_2x07_P1.27mm_Vertical_SMD
J3, J4: Conn_01x03; JST_XH_B3B-XH-A_1x03_P2.50mm_Vertical
R1, R2, R3, R5, R6, R13, R18, R20, R21, R22, R23, R24, R25, R26, R27, R28, R29, R30, R31, R32, R33, R34: 1K; R_0603_1608Metric_Pad0.98x0.95mm_HandSolder
R4: 10k; R_0603_1608Metric_Pad0.98x0.95mm_HandSolder
R9, R10: 1M; R_0603_1608Metric_Pad0.98x0.95mm_HandSolder
R11, R14, R16: 10K; R_0603_1608Metric_Pad0.98x0.95mm_HandSolder
SW1, SW10: SW_DIP_x01; SW_DIP_SPSTx01_Slide_Copal_CHS-01B_W7.62mm_P1.27mm
SW2, SW3, SW4, SW5, SW6, SW8, SW9, SW11, SW12, SW13: SW_Push; SW_SPST_B3S-1000
SW7: SW_SPST; SW_SPST_B3S-1000
U1: STM32L412KBTx; LQFP-32_7x7mm_P0.8mm
U2: nRF24_Full; PinHeader_2x04_P2.54mm_Vertical
U3: MIC5219-3.3YMM; MSOP-8_3x3mm_P0.65mm
U4: PCA9685PW; TSSOP-28_4.4x9.7mm_P0.65mm
U5: PCF8574TS; SSOP-20_4.4x6.5mm_P0.65mm

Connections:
A_Button: SW2.2, U1.10 (PA4)
B_Button: SW3.2, U1.6 (PA0)
CSN_nRF24: U1.25 (PA15), U2.4 (CSN)
DC_Button: SW11.2, U1.31 (PH3)
DIODE_CLK: R14.2, U1.26 (PB3), U4.26 (SCL)
DIODE_OE: R16.1, U4.23 (~OE), U5.12 (P2)
DIODE_SDA: R11.1, U1.28 (PB5), U4.27 (SDA)
Digital_Out_Put: U1.12 (PA6), U2.7 (MISO)
GND: C1.2, C2.2, C3.2, C4.2, C5.2, C6.2, C9.2, C10.2, D2.1 (K), H1.1, H2.1, H3.1, H4.1, H5.1, H6.1, J1.2, J2.5, J2.7, J2.11, J3.2, J4.2, R1.2, R2.2, R4.2, R10.2, R13.2, R18.2, R20.2, R21.2, R22.2, R23.2, R24.2, R25.2, R26.2, R27.2, R28.2, R29.2, R30.2, R31.2, R32.2, R33.2, R34.2, SW2.1, SW3.1, SW4.1, SW5.1, SW6.1, SW7.1 (A), SW8.1, SW9.1, SW11.1, SW12.1, SW13.1, U1.16 (VSS), U1.32 (VSS), U2.1 (GND), U3.5 (GND), U3.6 (GND), U3.7 (GND), U3.8 (GND), U4.2 (A1), U4.4 (A3), U4.14 (VSS), U4.24 (A5), U4.25 (EXTCLK), U5.1 (~INT), U5.6 (A0), U5.7 (A1), U5.9 (A2), U5.15 (VSS)
GPIO_EX_CLK: R5.2, U1.18 (PA8), U5.2 (SCL)
GPIO_EX_SERIAL_DATA: R6.2, U1.22 (PA12), U5.4 (SDA)
Glob_Alim: C1.1, C3.1, C5.1, C6.1, C7.2, C10.1, J2.3, J3.1, J4.1, R3.1, R5.1, R6.1, R11.2, R14.1, R16.2, SW10.2, U1.1 (VDD), U1.5 (VDDA), U1.17 (VDD), U2.2 (VCC), U3.3 (OUT), U4.1 (A0), U4.3 (A2), U4.5 (A4), U4.28 (VDD), U5.5 (VDD)
L: J4.3, R13.1, U1.3 (PC15)
LC_Button: SW8.2, U1.2 (PC14)
Li-ion: C4.1, J1.1, R9.1, SW1.1
MOSI: U1.13 (PA7), U2.6 (MOSI)
NES/SNES_switcher: R1.1, SW10.1, U1.19 (PA9)
unnamed: C7.1, R4.1
unnamed: D2.2 (A), R3.2
unnamed: D3.2 (A), U4.9 (LED3)
unnamed: D3.1 (K), R18.1
unnamed: D4.2 (A), U4.8 (LED2)
unnamed: D4.1 (K), R20.1
unnamed: D5.2 (A), U4.7 (LED1)
unnamed: D5.1 (K), R21.1
unnamed: D6.2 (A), U4.6 (LED0)
unnamed: D6.1 (K), R22.1
unnamed: D7.2 (A), U4.10 (LED4)
unnamed: D7.1 (K), R23.1
unnamed: D8.2 (A), U4.11 (LED5)
unnamed: D8.1 (K), R24.1
unnamed: D9.2 (A), U4.12 (LED6)
unnamed: D9.1 (K), R25.1
unnamed: D10.2 (A), U4.13 (LED7)
unnamed: D10.1 (K), R26.1
unnamed: D11.2 (A), U4.22 (LED15)
unnamed: D11.1 (K), R27.1
unnamed: D12.2 (A), U4.21 (LED14)
unnamed: D12.1 (K), R28.1
unnamed: D13.2 (A), U4.20 (LED13)
unnamed: D13.1 (K), R29.1
unnamed: D14.2 (A), U4.19 (LED12)
unnamed: D14.1 (K), R30.1
unnamed: D15.2 (A), U4.18 (LED11)
unnamed: D15.1 (K), R31.1
unnamed: D16.2 (A), U4.17 (LED10)
unnamed: D16.1 (K), R32.1
unnamed: D17.2 (A), U4.16 (LED9)
unnamed: D17.1 (K), R33.1
unnamed: D18.2 (A), U4.15 (LED8)
unnamed: D18.1 (K), R34.1
unnamed: C9.1, U3.4 (BP)
unnamed: SW1.2, U3.2 (IN)
Order_Search: SW7.2 (B), U1.7 (PA1)
POWER_CHECK: C2.1, R9.2, R10.1, U1.27 (PB4)
Pin_Clock: U1.11 (PA5), U2.5 (SCK)
R: J3.3, R2.1, U1.20 (PA10)
RC_Button: SW9.2, U1.30 (PB7)
RX/TX: U1.21 (PA11), U2.3 (CE)
Reset_Buton: J2.12, U1.4 (NRST)
SE_Button: SW13.2, U1.15 (PB1)
ST_Button: SW12.2, U5.11 (P1)
SWDCK: J2.6, U1.24 (PA14)
SWDIO: J2.4, U1.23 (PA13)
UC_Button: SW6.2, U1.29 (PB6)
USART2_RX: J2.13, U1.9 (PA3)
USART2_TX: J2.14, U1.8 (PA2)
X_Button: SW4.2, U1.14 (PB0)
Y_Button: SW5.2, U5.10 (P0)

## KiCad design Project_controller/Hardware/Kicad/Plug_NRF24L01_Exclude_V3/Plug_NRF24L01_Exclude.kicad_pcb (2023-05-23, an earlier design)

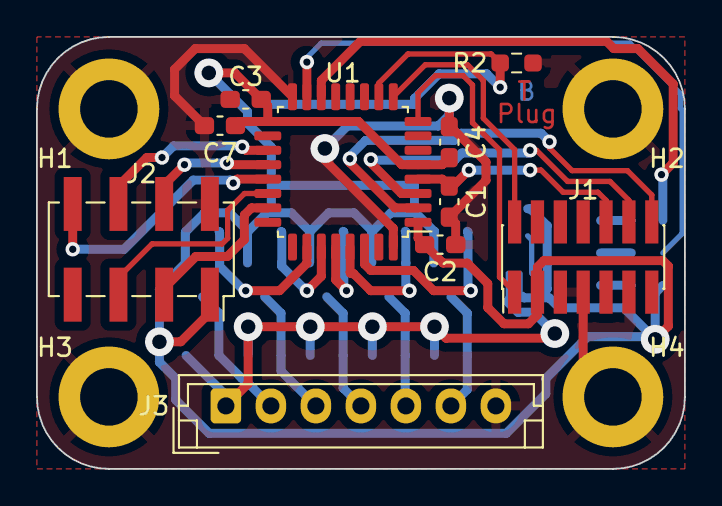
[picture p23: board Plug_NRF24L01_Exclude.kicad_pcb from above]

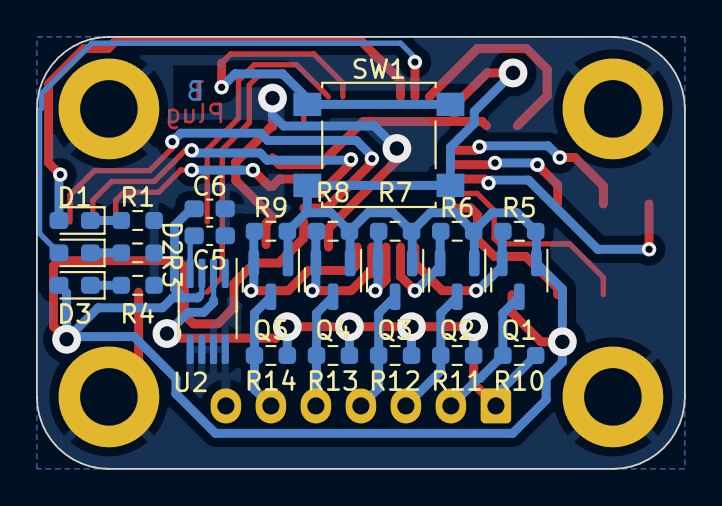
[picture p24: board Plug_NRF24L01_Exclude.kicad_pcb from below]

Board: 2 copper layers, 36.0 x 24.0 mm, 39 parts (25 on the bottom side), 30 nets.

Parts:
C1, C2, C3, C4: 100n; C_0603_1608Metric_Pad1.08x0.95mm_HandSolder
C5: 470p; C_0603_1608Metric_Pad1.08x0.95mm_HandSolder
C6: 2.2u; C_0603_1608Metric_Pad1.08x0.95mm_HandSolder
C7: 10u; C_0603_1608Metric_Pad1.08x0.95mm_HandSolder
D1, D2: LED_Small; D_0603_1608Metric_Pad1.05x0.95mm_HandSolder
D3: LED; D_0603_1608Metric_Pad1.05x0.95mm_HandSolder
H1, H2, H3, H4: MountingHole_Pad; MountingHole_3.2mm_M3_DIN965_Pad
J1: Conn_02x07_Odd_Even; PinHeader_2x07_P1.27mm_Vertical_SMD
J2: Conn_01x08_Socket; PinSocket_2x04_P2.54mm_Vertical_SMD
J3: Conn_01x07_Socket; JST_EH_B7B-EH-A_1x07_P2.50mm_Vertical
Q1, Q2, Q3, Q4, Q5: 2N7002; SOT-23
R1, R3, R4: 1k; R_0603_1608Metric_Pad0.98x0.95mm_HandSolder
R2, R5, R6, R7, R8, R9, R10, R11, R12, R13, R14: 10k; R_0603_1608Metric_Pad0.98x0.95mm_HandSolder
SW1: SW_SPST; SW_SPST_B3S-1000
U1: STM32L412KBTx; LQFP-32_7x7mm_P0.8mm
U2: MIC5219-3.3YMM; MSOP-8_3x3mm_P0.65mm

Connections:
+3.3V: C2.1, C3.1, C4.1, C6.1, C7.1, D3.2 (A), J1.3, J2.1, Q1.1 (G), Q2.1 (G), Q3.1 (G), Q4.1 (G), Q5.1 (G), R5.1, R6.1, R7.1, R8.1, R9.1, SW1.2 (B), U1.1 (VDD), U1.5 (VDDA), U1.17 (VDD), U2.3 (OUT)
+5V: J3.1, R10.1, R11.1, R12.1, R13.1, R14.1, U2.2 (IN)
Appairing_Btn: R2.1, SW1.1 (A), U1.10 (PA4)
Chip_Enable: J2.4, U1.20 (PA10)
Data_Clock_SNES: J3.2, Q1.3 (D), R10.2
Data_Clock_STM32: Q1.2 (S), R5.2, U1.26 (PB3)
Data_Latch_SNES: J3.3, Q2.3 (D), R11.2
Data_Latch_STM32: Q2.2 (S), R6.2, U1.27 (PB4)
GND: C1.1, C2.2, C3.2, C4.2, C5.2, C6.2, C7.2, H1.1, H2.1, H3.1, H4.1, J1.5, J1.7, J1.11, J2.2, J3.7, R1.2, R2.2, R3.2, R4.2, U1.16 (VSS), U1.32 (VSS), U2.5 (GND), U2.6 (GND), U2.7 (GND), U2.8 (GND)
IOBit_SNES: J3.6, Q5.3 (D), R14.2
IOBit_STM32: Q5.2 (S), R9.2, U1.30 (PB7)
NRST: C1.2, J1.10, U1.4 (NRST)
unnamed: D1.1 (K), R1.1
unnamed: D2.1 (K), R3.1
unnamed: D3.1 (K), R4.1
unnamed: C5.1, U2.4 (BP)
Player1_LED: D1.2 (A), U1.14 (PB0)
SPI_Chip_Select: J2.3, U1.23 (PA13)
SPI_Clock: J2.6, U1.19 (PA9)
SPI_Digital_Input: J2.8, U1.21 (PA11)
SPI_Digital_Output: J2.5, U1.22 (PA12)
SWDCK: J1.1, U1.8 (PA2)
SWDIO: J1.2, U1.9 (PA3)
Serial_Data1_SNES: J3.4, Q3.3 (D), R12.2
Serial_Data1_STM32: Q3.2 (S), R7.2, U1.28 (PB5)
Serial_Data2_SNES: J3.5, Q4.3 (D), R13.2
Serial_Data2_STM32: Q4.2 (S), R8.2, U1.29 (PB6)
Status_LED: D2.2 (A), U1.15 (PB1)
USART2_RX: J1.12, U1.3 (PC15)
USART2_TX: J1.14, U1.2 (PC14)

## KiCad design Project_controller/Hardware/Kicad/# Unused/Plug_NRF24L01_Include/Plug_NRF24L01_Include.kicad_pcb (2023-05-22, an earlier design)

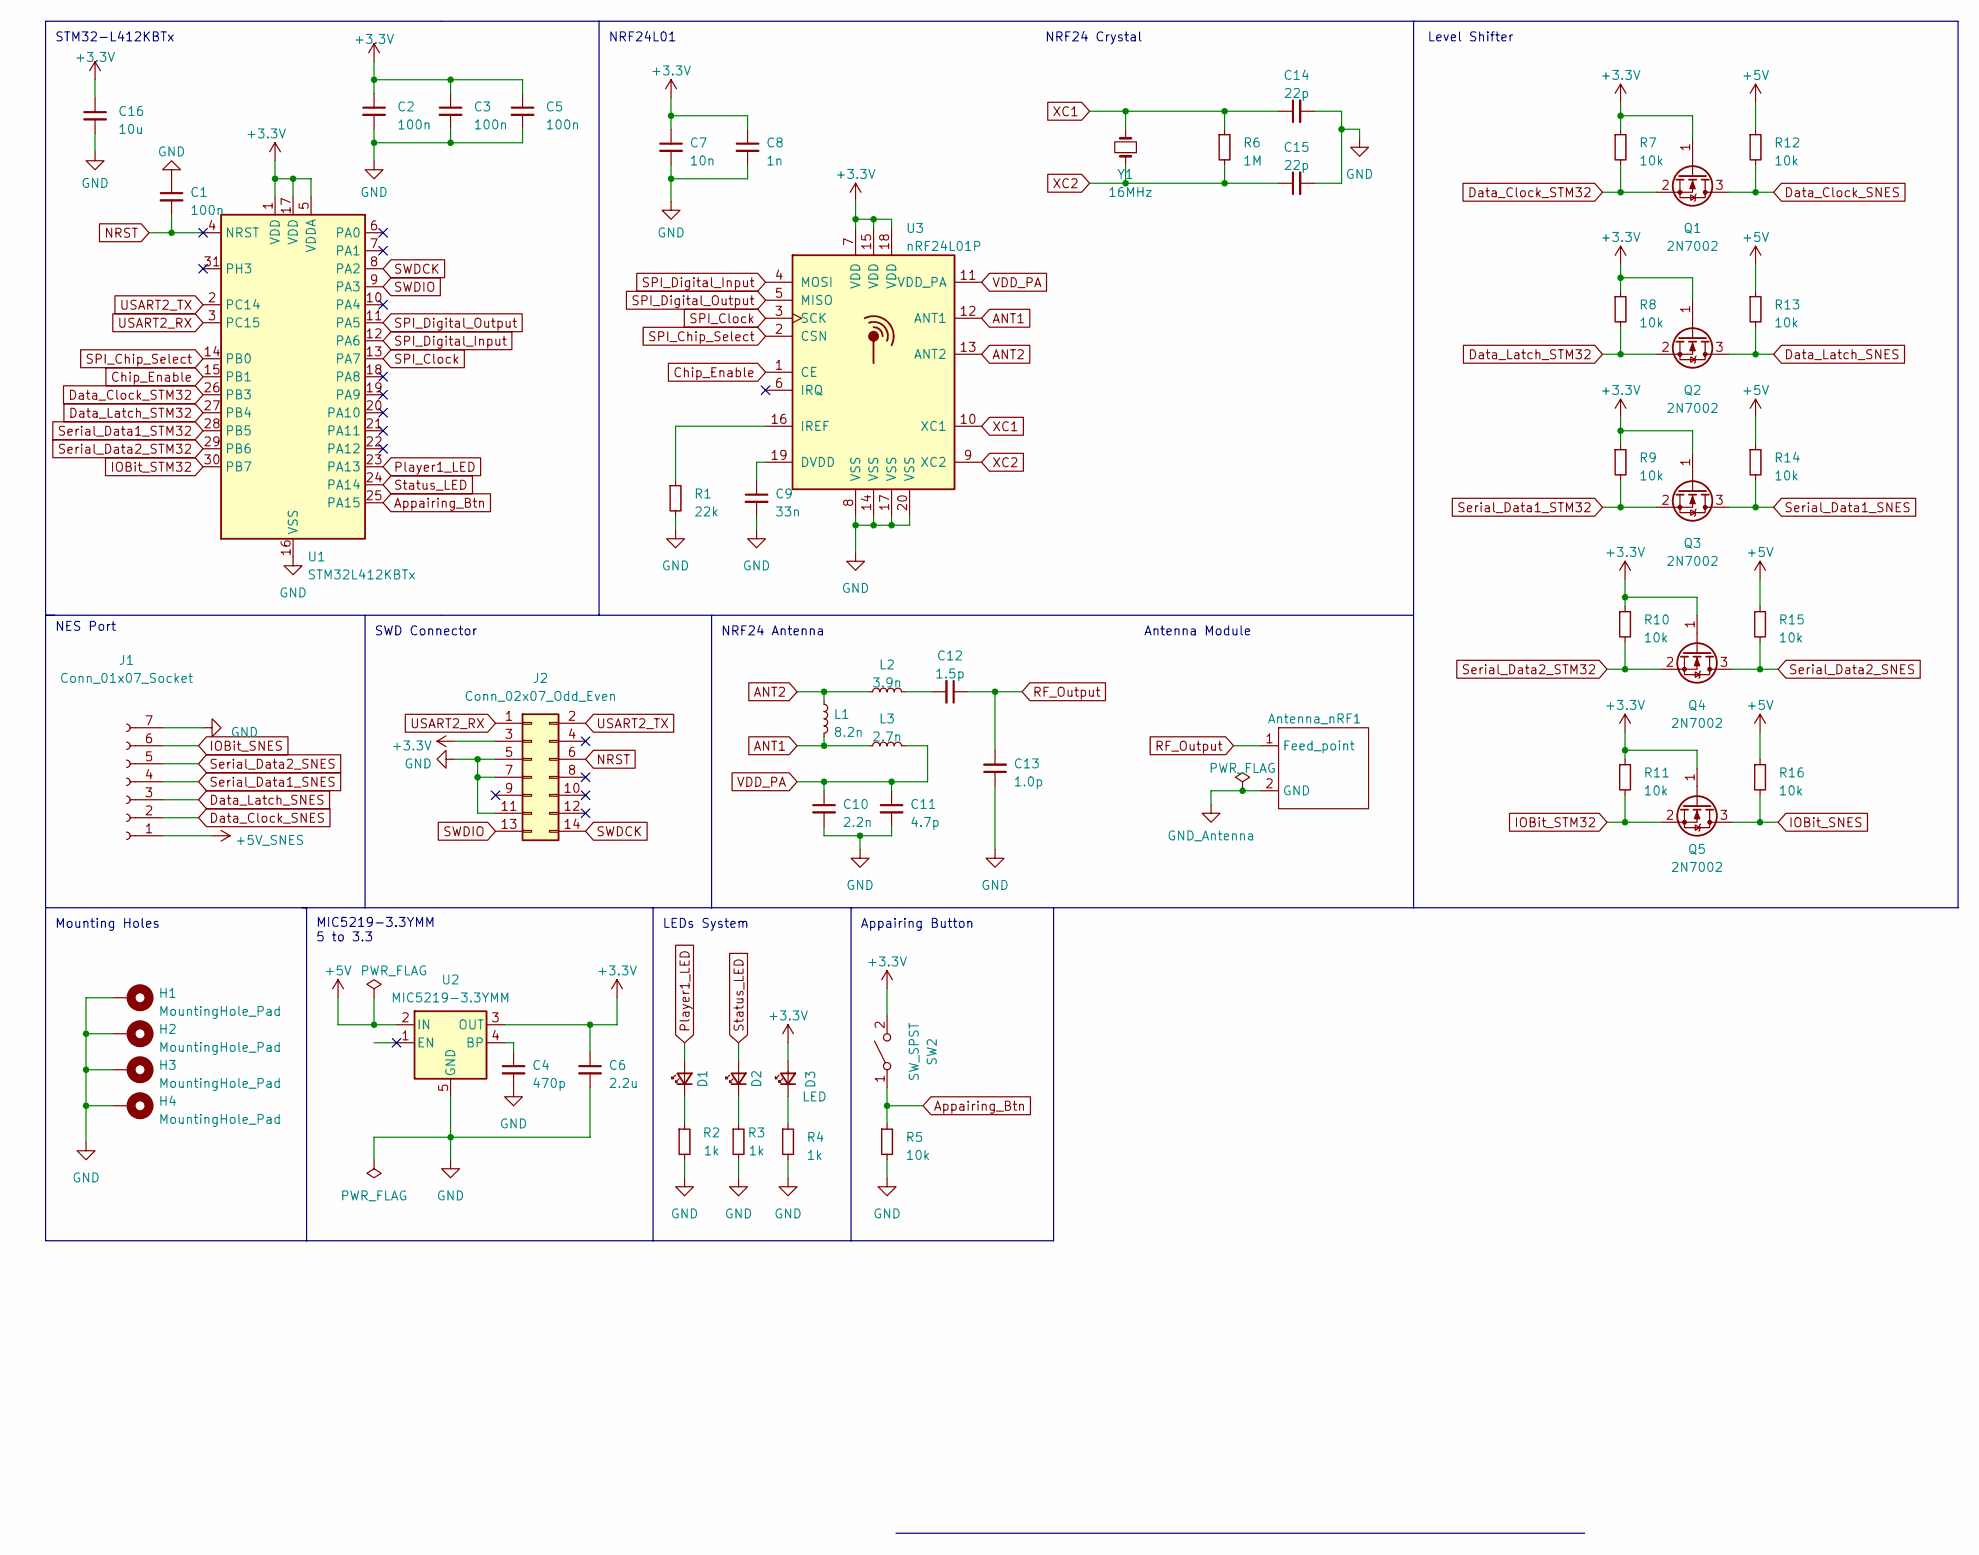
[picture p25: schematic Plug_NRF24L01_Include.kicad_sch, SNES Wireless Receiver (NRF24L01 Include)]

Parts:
Antenna_nRF1: Texas_SWRA117D_2.4GHz_Right
C1, C2, C3, C5: 100n; C_0603_1608Metric_Pad1.08x0.95mm_HandSolder
C4: 470p; C_0603_1608Metric_Pad1.08x0.95mm_HandSolder
C6: 2.2u; C_0603_1608Metric_Pad1.08x0.95mm_HandSolder
C7: 10n; C_0603_1608Metric_Pad1.08x0.95mm_HandSolder
C8: 1n; C_0603_1608Metric_Pad1.08x0.95mm_HandSolder
C9: 33n; C_0603_1608Metric_Pad1.08x0.95mm_HandSolder
C10: 2.2n; C_0603_1608Metric_Pad1.08x0.95mm_HandSolder
C11: 4.7p; C_0603_1608Metric_Pad1.08x0.95mm_HandSolder
C12: 1.5p; C_0603_1608Metric_Pad1.08x0.95mm_HandSolder
C13: 1.0p; C_0603_1608Metric_Pad1.08x0.95mm_HandSolder
C14, C15: 22p; C_0603_1608Metric_Pad1.08x0.95mm_HandSolder
C16: 10u; C_0603_1608Metric_Pad1.08x0.95mm_HandSolder
D1, D2: LED_Small; D_0603_1608Metric_Pad1.05x0.95mm_HandSolder
D3: LED; D_0603_1608Metric_Pad1.05x0.95mm_HandSolder
H1, H2, H3, H4: MountingHole_Pad; MountingHole_3.2mm_M3_DIN965_Pad
J1: Conn_01x07_Socket; JST_EH_B7B-EH-A_1x07_P2.50mm_Vertical
J2: Conn_02x07_Odd_Even; PinHeader_2x07_P1.27mm_Vertical_SMD
L1: 8.2n; L_0805_2012Metric_Pad1.05x1.20mm_HandSolder
L2: 3.9n; L_0805_2012Metric_Pad1.05x1.20mm_HandSolder
L3: 2.7n; L_0805_2012Metric_Pad1.05x1.20mm_HandSolder
Q1, Q2, Q3, Q4, Q5: 2N7002; SOT-23
R1: 22k; R_0603_1608Metric_Pad0.98x0.95mm_HandSolder
R2, R3, R4: 1k; R_0603_1608Metric_Pad0.98x0.95mm_HandSolder
R5, R7, R8, R9, R10, R11, R12, R13, R14, R15, R16: 10k; R_0603_1608Metric_Pad0.98x0.95mm_HandSolder
R6: 1M; R_0603_1608Metric_Pad0.98x0.95mm_HandSolder
SW2: SW_SPST; SW_SPST_B3S-1000
U1: STM32L412KBTx; LQFP-32_7x7mm_P0.8mm
U2: MIC5219-3.3YMM; MSOP-8_3x3mm_P0.65mm
U3: nRF24L01P; QFN-20-1EP_4x4mm_P0.5mm_EP2.5x2.5mm
Y1: 16MHz; Crystal_SMD_HC49-SD_HandSoldering

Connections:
+3.3V: C2.1, C3.1, C5.1, C6.1, C7.1, C8.1, C16.1, D3.2 (A), J2.3, Q1.1 (G), Q2.1 (G), Q3.1 (G), Q4.1 (G), Q5.1 (G), R7.1, R8.1, R9.1, R10.1, R11.1, SW2.2 (B), U1.1 (VDD), U1.5 (VDDA), U1.17 (VDD), U2.3 (OUT), U3.7 (VDD), U3.15 (VDD), U3.18 (VDD)
ANT1: L1.2, L3.1, U3.12 (ANT1)
ANT2: L1.1, L2.1, U3.13 (ANT2)
Appairing_Btn: R5.1, SW2.1 (A), U1.25 (PA15)
Chip_Enable: U1.15 (PB1), U3.1 (CE)
Data_Clock_SNES: J1.2, Q1.3 (D), R12.2
Data_Clock_STM32: Q1.2 (S), R7.2, U1.26 (PB3)
Data_Latch_SNES: J1.3, Q2.3 (D), R13.2
Data_Latch_STM32: Q2.2 (S), R8.2, U1.27 (PB4)
GND: C1.1, C2.2, C3.2, C4.2, C5.2, C6.2, C7.2, C8.2, C9.2, C10.2, C11.2, C13.1, C14.2, C15.2, C16.2, H1.1, H2.1, H3.1, H4.1, J1.7, J2.5, J2.7, J2.11, R1.2, R2.2, R3.2, R4.2, R5.2, U1.16 (VSS), U1.32 (VSS), U2.5 (GND), U2.6 (GND), U2.7 (GND), U2.8 (GND), U3.8 (VSS), U3.14 (VSS), U3.17 (VSS), U3.20 (VSS)
GND2: Antenna_nRF1.2 (GND)
IOBit_SNES: J1.6, Q5.3 (D), R16.2
IOBit_STM32: Q5.2 (S), R11.2, U1.30 (PB7)
NRST: C1.2, J2.6, U1.4 (NRST)
unnamed: C12.2, L2.2
unnamed: D1.1 (K), R2.1
unnamed: D2.1 (K), R3.1
unnamed: D3.1 (K), R4.1
unnamed: C4.1, U2.4 (BP)
unnamed: C9.1, U3.19 (DVDD)
unnamed: R1.1, U3.16 (IREF)
Player1_LED: D1.2 (A), U1.23 (PA13)
RF_Output: Antenna_nRF1.1 (Feed_point), C12.1, C13.2
SPI_Chip_Select: U1.14 (PB0), U3.2 (CSN)
SPI_Clock: U1.13 (PA7), U3.3 (SCK)
SPI_Digital_Input: U1.12 (PA6), U3.4 (MOSI)
SPI_Digital_Output: U1.11 (PA5), U3.5 (MISO)
SWDCK: J2.14, U1.8 (PA2)
SWDIO: J2.13, U1.9 (PA3)
Serial_Data1_SNES: J1.4, Q3.3 (D), R14.2
Serial_Data1_STM32: Q3.2 (S), R9.2, U1.28 (PB5)
Serial_Data2_SNES: J1.5, Q4.3 (D), R15.2
Serial_Data2_STM32: Q4.2 (S), R10.2, U1.29 (PB6)
Status_LED: D2.2 (A), U1.24 (PA14)
USART2_RX: J2.1, U1.3 (PC15)
USART2_TX: J2.2, U1.2 (PC14)
VDD_PA: C10.1, C11.1, L3.2, U3.11 (VDD_PA)
XC1: C14.1, R6.1, U3.10 (XC1), Y1.2
XC2: C15.1, R6.2, U3.9 (XC2), Y1.1

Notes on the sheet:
Mounting Holes
NRF24 Antenna
Antenna Module
SWD Connector
NES Port
Appairing Button
LEDs System
STM32-L412KBTx
MIC5219-3.3YMM 5 to 3.3
NRF24L01
NRF24 Crystal
Level Shifter

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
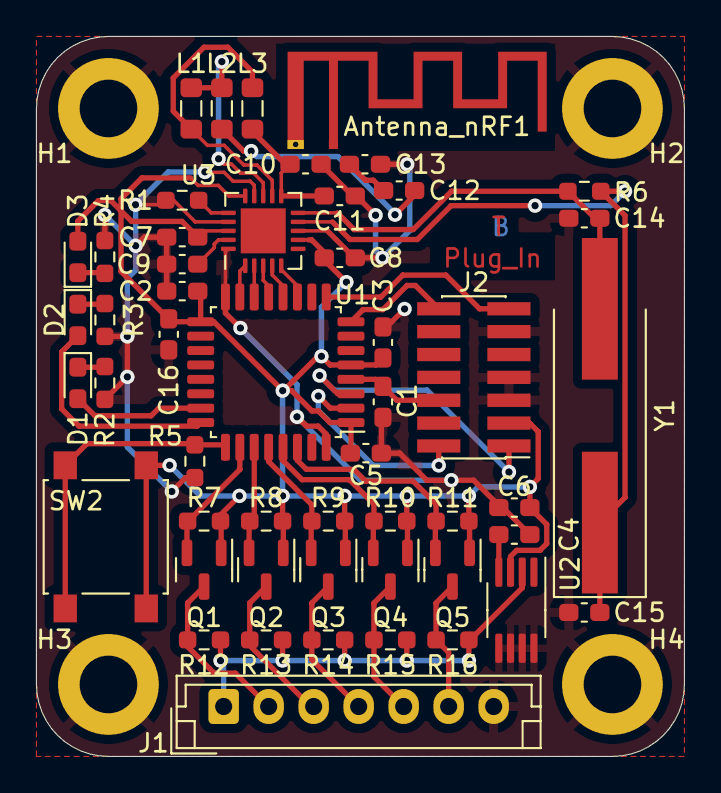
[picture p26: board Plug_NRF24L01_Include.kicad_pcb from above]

Board: 2 copper layers, 36.0 x 40.0 mm, 55 parts (0 on the bottom side), 39 nets.

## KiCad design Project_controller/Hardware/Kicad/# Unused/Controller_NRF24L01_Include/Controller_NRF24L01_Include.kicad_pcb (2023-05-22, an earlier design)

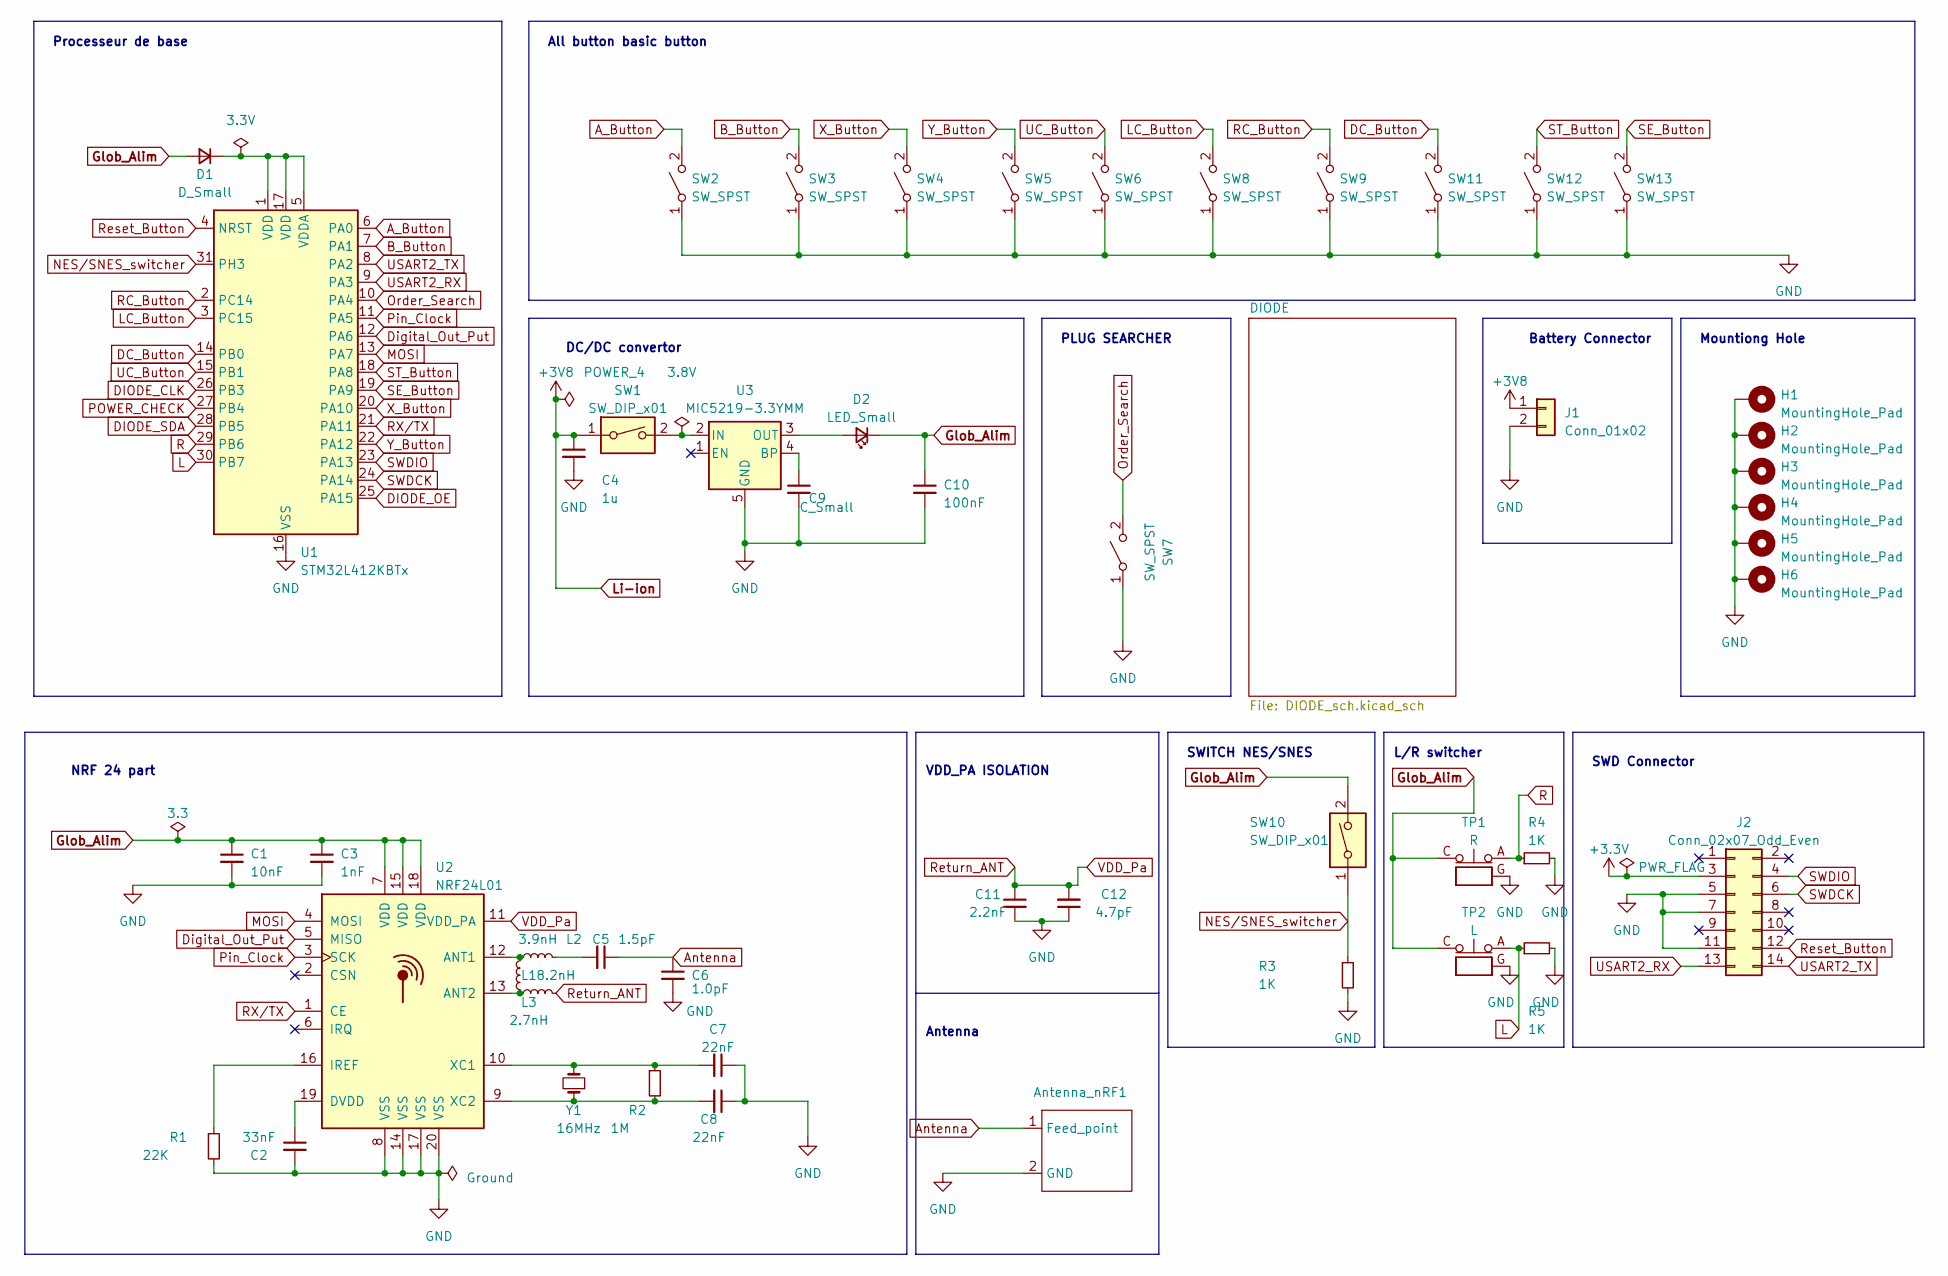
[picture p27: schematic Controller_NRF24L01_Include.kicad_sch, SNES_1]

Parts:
Antenna_nRF1: Texas_SWRA117D_2.4GHz_Right
C1: 10nF; C_0603_1608Metric_Pad1.08x0.95mm_HandSolder
C2: 33nF; C_0603_1608Metric_Pad1.08x0.95mm_HandSolder
C3: 1nF; C_0603_1608Metric_Pad1.08x0.95mm_HandSolder
C4: 1u; C_0603_1608Metric_Pad1.08x0.95mm_HandSolder
C5: 1.5pF; C_0402_1005Metric_Pad0.74x0.62mm_HandSolder
C6: 1.0pF; C_0402_1005Metric_Pad0.74x0.62mm_HandSolder
C7, C8: 22nF; C_0603_1608Metric_Pad1.08x0.95mm_HandSolder
C9: C_Small; C_0603_1608Metric_Pad1.08x0.95mm_HandSolder
C10: 100nF; C_0603_1608Metric_Pad1.08x0.95mm_HandSolder
C11: 2.2nF; C_0402_1005Metric_Pad0.74x0.62mm_HandSolder
C12: 4.7pF; C_0402_1005Metric_Pad0.74x0.62mm_HandSolder
D1: D_Small; D_0603_1608Metric_Pad1.05x0.95mm_HandSolder
D2: LED_Small; LED_0603_1608Metric_Pad1.05x0.95mm_HandSolder
H1, H2, H3, H4, H5, H6: MountingHole_Pad; MountingHole_3.2mm_M3_DIN965_Pad
J1: Conn_01x02; JST_XH_B2B-XH-A_1x02_P2.50mm_Vertical
J2: Conn_02x07_Odd_Even; PinHeader_2x07_P1.27mm_Vertical_SMD
L1: 8.2nH; L_0603_1608Metric_Pad1.05x0.95mm_HandSolder
L2: 3.9nH; L_0603_1608Metric_Pad1.05x0.95mm_HandSolder
L3: 2.7nH; L_0402_1005Metric_Pad0.77x0.64mm_HandSolder
R1: 22K; R_0603_1608Metric_Pad0.98x0.95mm_HandSolder
R2: 1M; R_0603_1608Metric_Pad0.98x0.95mm_HandSolder
R3, R4, R5: 1K; R_0603_1608Metric_Pad0.98x0.95mm_HandSolder
SW1, SW10: SW_DIP_x01; SW_DIP_SPSTx01_Slide_Copal_CHS-01B_W7.62mm_P1.27mm
SW2, SW3, SW4, SW5, SW6, SW7, SW8, SW9, SW11, SW12, SW13: SW_SPST; SW_SPST_B3S-1000
TP1: R; SMA_Molex_73251-1153_EdgeMount_Horizontal
TP2: L; SMA_Molex_73251-1153_EdgeMount_Horizontal
U1: STM32L412KBTx; LQFP-32_7x7mm_P0.8mm
U2: NRF24L01; QFN-20-1EP_4x4mm_P0.5mm_EP2.5x2.5mm
U3: MIC5219-3.3YMM; MSOP-8_3x3mm_P0.65mm
Y1: 16MHz; Crystal_SMD_HC49-SD_HandSoldering

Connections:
+3.3V: J2.3
A_Button: SW2.2 (B), U1.6 (PA0)
Antenna: Antenna_nRF1.1 (Feed_point), C5.1, C6.1
B_Button: SW3.2 (B), U1.7 (PA1)
DC_Button: SW11.2 (B), U1.14 (PB0)
DIODE_CLK: U1.26 (PB3); also elsewhere on the board
DIODE_OE: U1.25 (PA15); also elsewhere on the board
DIODE_SDA: U1.28 (PB5); also elsewhere on the board
Digital_Out_Put: U1.12 (PA6), U2.5 (MISO)
GND: Antenna_nRF1.2 (GND), C1.2, C2.2, C3.2, C4.2, C6.2, C7.1, C8.1, C9.2, C10.2, C11.2, C12.1, H1.1, H2.1, H3.1, H4.1, H5.1, H6.1, J1.2, J2.5, J2.7, J2.11, R1.2, R3.2, R4.2, R5.2, SW2.1 (A), SW3.1 (A), SW4.1 (A), SW5.1 (A), SW6.1 (A), SW7.1 (A), SW8.1 (A), SW9.1 (A), SW11.1 (A), SW12.1 (A), SW13.1 (A), TP1.G, TP2.G, U1.16 (VSS), U1.32 (VSS), U2.8 (VSS), U2.14 (VSS), U2.17 (VSS), U2.20 (VSS), U3.5 (GND), U3.6 (GND), U3.7 (GND), U3.8 (GND); also elsewhere on the board
Glob_Alim: C1.1, C3.1, C10.1, D1.2 (A), D2.1 (K), SW10.2, TP1.C, TP2.C, U2.7 (VDD), U2.15 (VDD), U2.18 (VDD); also elsewhere on the board
L: R5.1, TP2.A, U1.30 (PB7)
LC_Button: SW8.2 (B), U1.3 (PC15)
Li-ion: C4.1, J1.1, SW1.1; also elsewhere on the board
MOSI: U1.13 (PA7), U2.4 (MOSI)
NES/SNES_switcher: R3.1, SW10.1, U1.31 (PH3)
unnamed: D1.1 (K), U1.1 (VDD), U1.5 (VDDA), U1.17 (VDD)
unnamed: SW1.2, U3.2 (IN)
unnamed: C5.2, L2.2
unnamed: D2.2 (A), U3.3 (OUT)
unnamed: L1.2, L2.1, U2.12 (ANT1)
unnamed: L1.1, L3.1, U2.13 (ANT2)
unnamed: C2.1, U2.19 (DVDD)
unnamed: R1.1, U2.16 (IREF)
unnamed: C7.2, R2.1, U2.10 (XC1), Y1.2
unnamed: C8.2, R2.2, U2.9 (XC2), Y1.1
unnamed: C9.1, U3.4 (BP)
Order_Search: SW7.2 (B), U1.10 (PA4)
POWER_CHECK: U1.27 (PB4); also elsewhere on the board
Pin_Clock: U1.11 (PA5), U2.3 (SCK)
R: R4.1, TP1.A, U1.29 (PB6)
RC_Button: SW9.2 (B), U1.2 (PC14)
RX/TX: U1.21 (PA11), U2.1 (CE)
Reset_Button: J2.12, U1.4 (NRST)
Return_ANT: C11.1, C12.2, L3.2, U2.11 (VDD_PA)
SE_Button: SW13.2 (B), U1.19 (PA9)
ST_Button: SW12.2 (B), U1.18 (PA8)
SWDCK: J2.6, U1.24 (PA14)
SWDIO: J2.4, U1.23 (PA13)
UC_Button: SW6.2 (B), U1.15 (PB1)
USART2_RX: J2.13, U1.9 (PA3)
USART2_TX: J2.14, U1.8 (PA2)
X_Button: SW4.2 (B), U1.20 (PA10)
Y_Button: SW5.2 (B), U1.22 (PA12)

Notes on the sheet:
L/R switcher
NRF 24 part
Antenna
Mountiong Hole
Processeur de base
PLUG SEARCHER
VDD_PA ISOLATION
All button basic button
Battery Connector
DC/DC convertor
SWD Connector
SWITCH NES/SNES

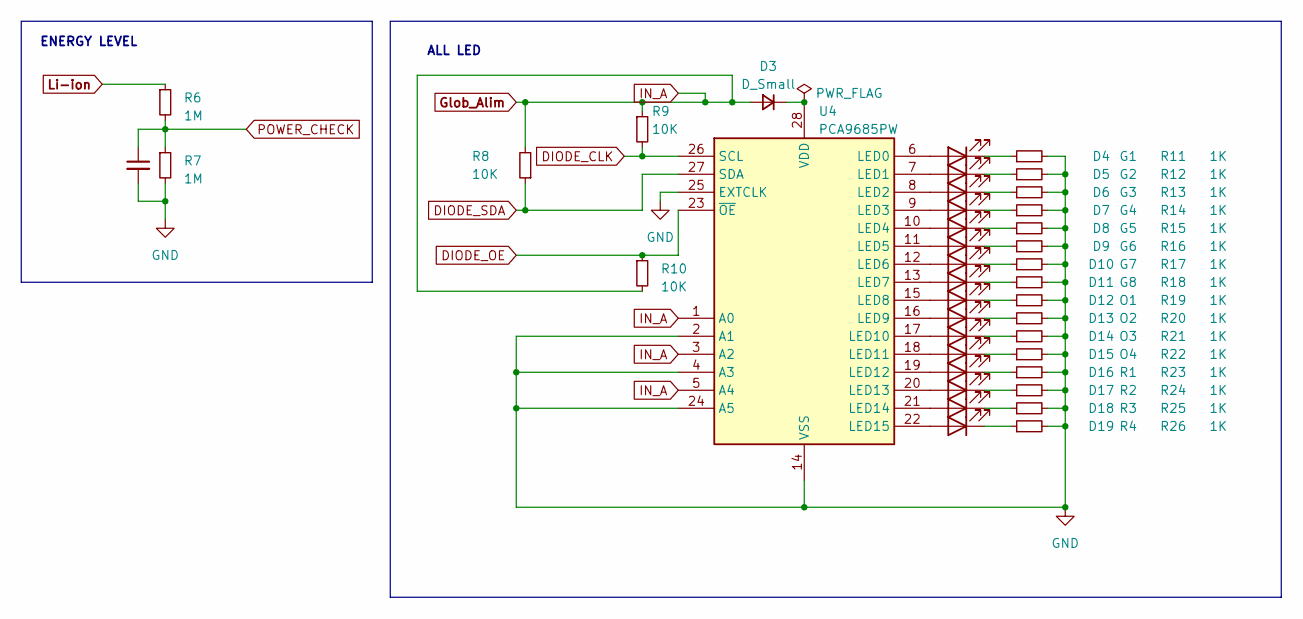
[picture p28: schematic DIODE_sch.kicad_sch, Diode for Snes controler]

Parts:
C13: 1nF; C_0603_1608Metric_Pad1.08x0.95mm_HandSolder
D3: D_Small; LED_0603_1608Metric_Pad1.05x0.95mm_HandSolder
D4: G1; LED_0603_1608Metric_Pad1.05x0.95mm_HandSolder
D5: G2; LED_0603_1608Metric_Pad1.05x0.95mm_HandSolder
D6: G3; LED_0603_1608Metric_Pad1.05x0.95mm_HandSolder
D7: G4; LED_0603_1608Metric_Pad1.05x0.95mm_HandSolder
D8: G5; LED_0603_1608Metric_Pad1.05x0.95mm_HandSolder
D9: G6; LED_0603_1608Metric_Pad1.05x0.95mm_HandSolder
D10: G7; LED_0603_1608Metric_Pad1.05x0.95mm_HandSolder
D11: G8; LED_0603_1608Metric_Pad1.05x0.95mm_HandSolder
D12: O1; LED_0603_1608Metric_Pad1.05x0.95mm_HandSolder
D13: O2; LED_0603_1608Metric_Pad1.05x0.95mm_HandSolder
D14: O3; LED_0603_1608Metric_Pad1.05x0.95mm_HandSolder
D15: O4; LED_0603_1608Metric_Pad1.05x0.95mm_HandSolder
D16: R1; LED_0603_1608Metric_Pad1.05x0.95mm_HandSolder
D17: R2; LED_0603_1608Metric_Pad1.05x0.95mm_HandSolder
D18: R3; LED_0603_1608Metric_Pad1.05x0.95mm_HandSolder
D19: R4; LED_0603_1608Metric_Pad1.05x0.95mm_HandSolder
R6, R7: 1M; R_0603_1608Metric_Pad0.98x0.95mm_HandSolder
R8, R9, R10: 10K; R_0603_1608Metric_Pad0.98x0.95mm_HandSolder
R11, R12, R13, R14, R15, R16, R17, R18, R19, R20, R21, R22, R23, R24, R25, R26: 1K; R_0603_1608Metric_Pad0.98x0.95mm_HandSolder
U4: PCA9685PW; TSSOP-28_4.4x9.7mm_P0.65mm

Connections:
DIODE_CLK: R9.2, U4.26 (SCL); also elsewhere on the board
DIODE_OE: R10.1, U4.23 (~OE); also elsewhere on the board
DIODE_SDA: R8.1, U4.27 (SDA); also elsewhere on the board
GND: C13.2, R7.2, R11.2, R12.2, R13.2, R14.2, R15.2, R16.2, R17.2, R18.2, R19.2, R20.2, R21.2, R22.2, R23.2, R24.2, R25.2, R26.2, U4.2 (A1), U4.4 (A3), U4.14 (VSS), U4.24 (A5), U4.25 (EXTCLK); also elsewhere on the board
Glob_Alim: D3.2 (A), R8.2, R9.1, R10.2, U4.1 (A0), U4.3 (A2), U4.5 (A4); also elsewhere on the board
Li-ion: R6.1; also elsewhere on the board
unnamed: D3.1 (K), U4.28 (VDD)
unnamed: D4.2 (A), U4.6 (LED0)
unnamed: D4.1 (K), R11.1
unnamed: D5.2 (A), U4.7 (LED1)
unnamed: D5.1 (K), R12.1
unnamed: D6.2 (A), U4.8 (LED2)
unnamed: D6.1 (K), R13.1
unnamed: D7.2 (A), U4.9 (LED3)
unnamed: D7.1 (K), R14.1
unnamed: D8.2 (A), U4.10 (LED4)
unnamed: D8.1 (K), R15.1
unnamed: D9.2 (A), U4.11 (LED5)
unnamed: D9.1 (K), R16.1
unnamed: D10.2 (A), U4.12 (LED6)
unnamed: D10.1 (K), R17.1
unnamed: D11.2 (A), U4.13 (LED7)
unnamed: D11.1 (K), R18.1
unnamed: D12.2 (A), U4.15 (LED8)
unnamed: D12.1 (K), R19.1
unnamed: D13.2 (A), U4.16 (LED9)
unnamed: D13.1 (K), R20.1
unnamed: D14.2 (A), U4.17 (LED10)
unnamed: D14.1 (K), R21.1
unnamed: D15.2 (A), U4.18 (LED11)
unnamed: D15.1 (K), R22.1
unnamed: D16.2 (A), U4.19 (LED12)
unnamed: D16.1 (K), R23.1
unnamed: D17.2 (A), U4.20 (LED13)
unnamed: D17.1 (K), R24.1
unnamed: D18.2 (A), U4.21 (LED14)
unnamed: D18.1 (K), R25.1
unnamed: D19.2 (A), U4.22 (LED15)
unnamed: D19.1 (K), R26.1
POWER_CHECK: C13.1, R6.2, R7.1; also elsewhere on the board

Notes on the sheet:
ALL LED
ENERGY LEVEL

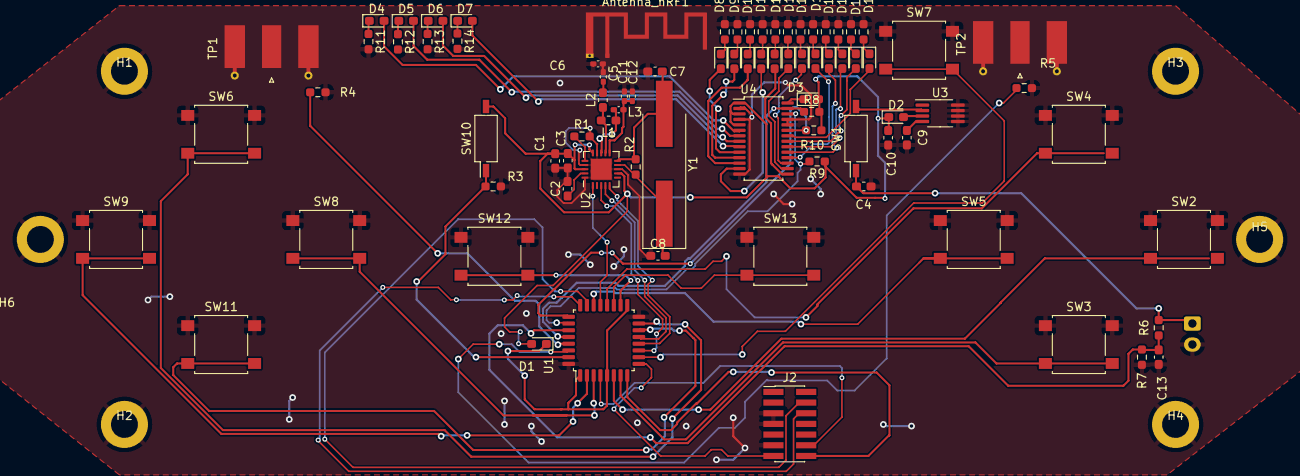
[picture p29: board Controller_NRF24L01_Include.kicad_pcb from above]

Board: 2 copper layers, 90 parts (1 on the bottom side), 76 nets.

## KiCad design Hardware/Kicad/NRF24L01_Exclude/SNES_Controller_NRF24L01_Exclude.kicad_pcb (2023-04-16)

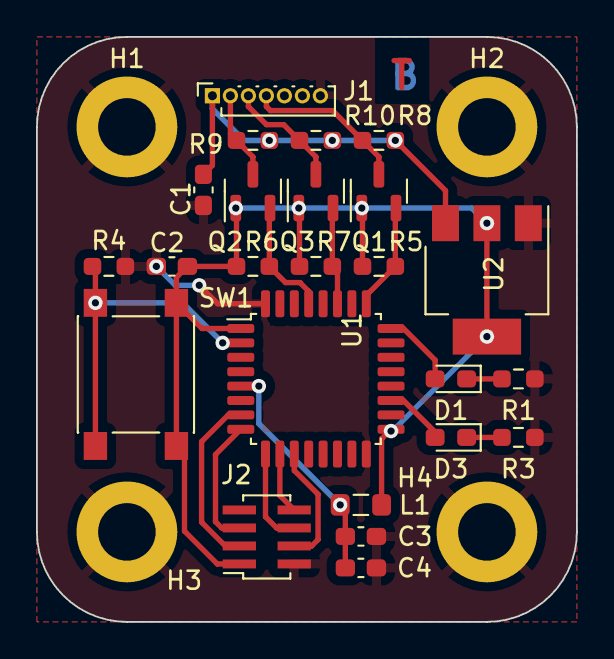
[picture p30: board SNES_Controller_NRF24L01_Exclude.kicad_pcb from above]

Board: 2 copper layers, 30.0 x 32.5 mm, 28 parts (0 on the bottom side), 20 nets.

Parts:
C1, C2, C3: 1u; C_0603_1608Metric_Pad1.08x0.95mm_HandSolder
C4: 10n; C_0603_1608Metric_Pad1.08x0.95mm_HandSolder
D1, D3: LED_Small; D_0603_1608Metric_Pad1.05x0.95mm_HandSolder
H1, H2, H3, H4: MountingHole_Pad; MountingHole_3.2mm_M3_DIN965_Pad
J1: Conn_01x07_Socket; PinSocket_1x07_P1.00mm_Vertical
J2: Conn_01x08_Socket; PinSocket_2x04_P1.00mm_Vertical_SMD
L1: 39n; L_0805_2012Metric_Pad1.05x1.20mm_HandSolder
Q1, Q2, Q3: 2N7002; SOT-23
R1, R3: 1k; R_0603_1608Metric_Pad0.98x0.95mm_HandSolder
R4, R5, R6, R7, R8, R9, R10: 10k; R_0603_1608Metric_Pad0.98x0.95mm_HandSolder
SW1: SW_Push; SW_Push_1P1T_NO_6x6mm_H9.5mm
U1: STM32L412KBTx; LQFP-32_7x7mm_P0.8mm
U2: AMS1117-3.3; SOT-223-3_TabPin2

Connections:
+3.3V: C2.1, J2.1, L1.1, Q1.1 (G), Q2.1 (G), Q3.1 (G), R5.1, R6.1, R7.1, SW1.1, U1.1 (VDD), U1.17 (VDD), U2.2 (VO)
+3.3VA: C3.1, C4.1, L1.2, U1.5 (VDDA)
+5V: C1.1, J1.1, R8.1, R9.1, R10.1, U2.3 (VI)
Appairing_Btn: R4.1, SW1.2, U1.2 (PC14)
Chip_Enable: J2.4, U1.11 (PA5)
Data_Clock_SNES: J1.2, Q2.3 (D), R9.2
Data_Clock_STM32: Q2.2 (S), R6.2, U1.29 (PB6)
Data_Latch_SNES: J1.3, Q3.3 (D), R10.2
Data_Latch_STM32: Q3.2 (S), R7.2, U1.27 (PB4)
GND: C1.2, C2.2, C3.2, C4.2, H1.1, H2.1, H3.1, H4.1, J1.7, J2.2, R1.2, R3.2, R4.2, U1.16 (VSS), U1.32 (VSS), U2.1 (GND)
unnamed: D1.1 (K), R1.1
unnamed: D3.1 (K), R3.1
Player1_LED: D1.2 (A), U1.24 (PA14)
SPI_Chip_Select: J2.3, U1.7 (PA1)
SPI_Clock: J2.6, U1.9 (PA3)
SPI_Digital_Input: J2.5, U1.8 (PA2)
SPI_Digital_Output: J2.8, U1.10 (PA4)
Serial_Data_SNES: J1.4, Q1.3 (D), R8.2
Serial_Data_STM32: Q1.2 (S), R5.2, U1.25 (PA15)
Status_LED: D3.2 (A), U1.19 (PA9)

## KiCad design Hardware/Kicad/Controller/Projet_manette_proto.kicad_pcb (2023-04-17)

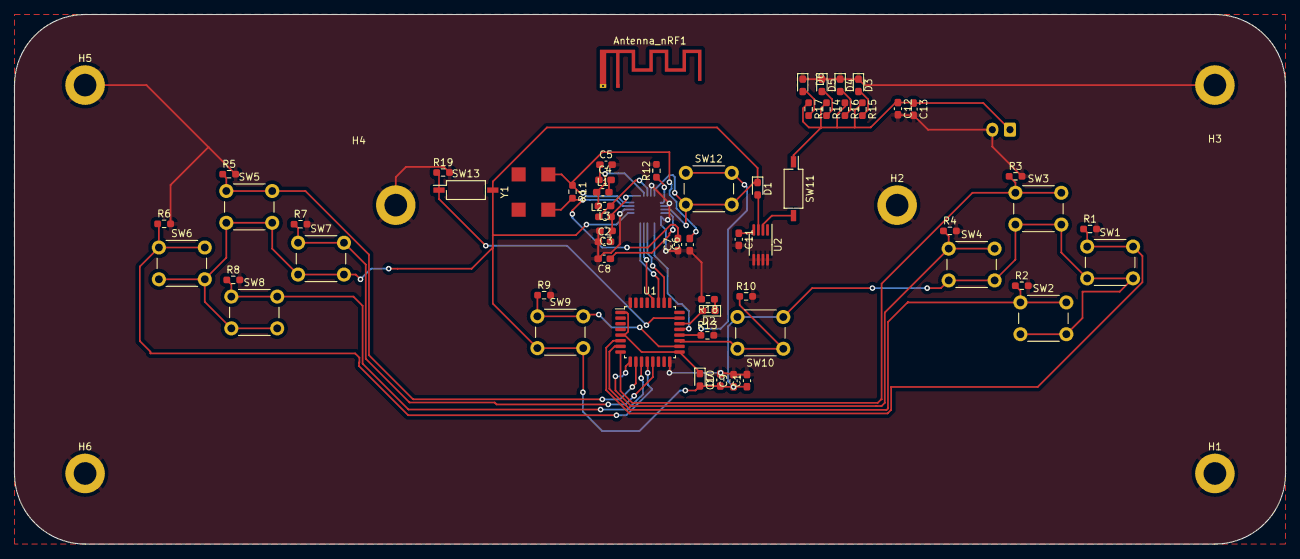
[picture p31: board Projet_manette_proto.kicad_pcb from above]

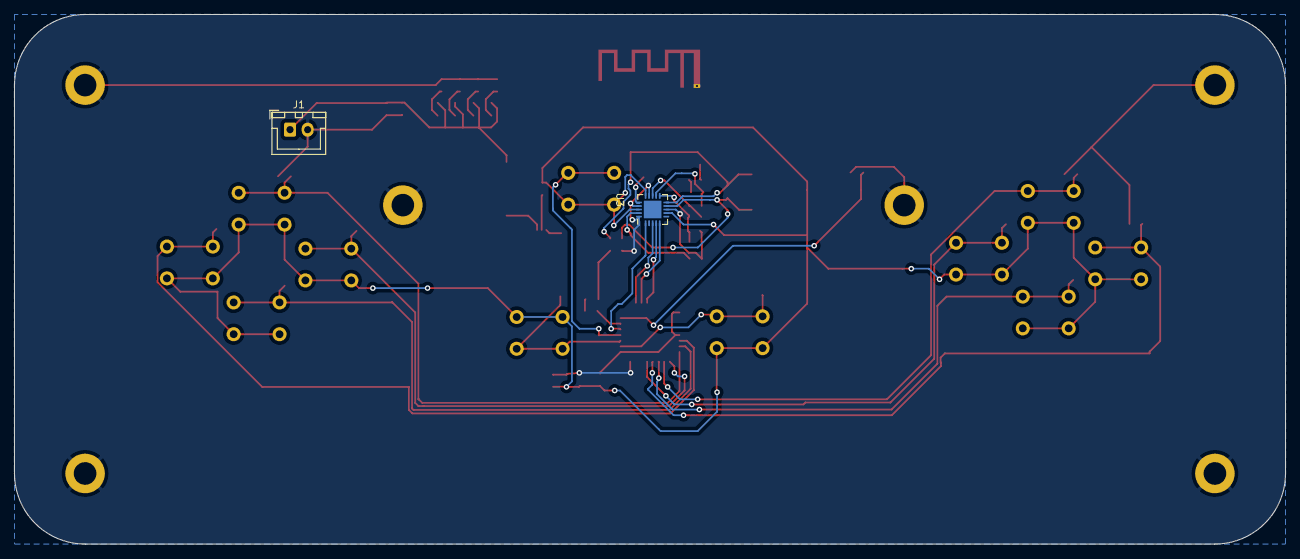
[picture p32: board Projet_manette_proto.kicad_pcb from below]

Board: 2 copper layers, 180.0 x 75.0 mm, 67 parts (2 on the bottom side), 38 nets.

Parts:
Antenna_nRF1: Texas_SWRA117D_2.4GHz_Right
C1: 100nF; C_0603_1608Metric_Pad1.08x0.95mm_HandSolder
C2: 4.7nF; C_0603_1608Metric_Pad1.08x0.95mm_HandSolder
C3: 2.2nF; C_0603_1608Metric_Pad1.08x0.95mm_HandSolder
C4: 1.5nF; C_0603_1608Metric_Pad1.08x0.95mm_HandSolder
C5: 1.0nF; C_0603_1608Metric_Pad1.08x0.95mm_HandSolder
C6, C7: 22nF; C_0603_1608Metric_Pad1.08x0.95mm_HandSolder
C8: 33nF; C_0603_1608Metric_Pad1.08x0.95mm_HandSolder
C9, C12: 1nF; C_0603_1608Metric_Pad1.08x0.95mm_HandSolder
C10: 10nF; C_0603_1608Metric_Pad1.08x0.95mm_HandSolder
C11: C_Small; C_0603_1608Metric_Pad1.08x0.95mm_HandSolder
C13: 1u; C_0603_1608Metric_Pad1.08x0.95mm_HandSolder
D1: LED_Small; LED_0603_1608Metric_Pad1.05x0.95mm_HandSolder
D2, D3, D4, D5, D6: LED; LED_0603_1608Metric_Pad1.05x0.95mm_HandSolder
D7: D_Small; D_0603_1608Metric_Pad1.05x0.95mm_HandSolder
H1, H2, H3, H4, H5, H6: MountingHole_Pad; MountingHole_3.2mm_M3_DIN965_Pad
J1: Conn_01x02; JST_XH_B2B-XH-A_1x02_P2.50mm_Vertical
L1: 3.9nH; L_0603_1608Metric_Pad1.05x0.95mm_HandSolder
L2: 2.7nF; L_0603_1608Metric_Pad1.05x0.95mm_HandSolder
L3: 8.2nF; L_0603_1608Metric_Pad1.05x0.95mm_HandSolder
R1, R2, R3, R4, R5, R6, R7, R8, R9, R10, R13, R18, R19: 1K; R_0603_1608Metric_Pad0.98x0.95mm_HandSolder
R11: 1M; R_0603_1608Metric_Pad0.98x0.95mm_HandSolder
R12: 22K; R_0603_1608Metric_Pad0.98x0.95mm_HandSolder
R14, R15, R16, R17: R_Small; R_0603_1608Metric_Pad0.98x0.95mm_HandSolder
SW1, SW2, SW3, SW4, SW5, SW6, SW7, SW8, SW9, SW10, SW12: SW_Push; SW_PUSH_6mm_H5mm
SW11, SW13: SW_DIP_x01; SW_DIP_SPSTx01_Slide_Copal_CHS-01B_W7.62mm_P1.27mm
U1: STM32L412KBTx; LQFP-32_7x7mm_P0.8mm
U2: MIC5219-3.3YMM; MSOP-8_3x3mm_P0.65mm
U3: NRF24L01; QFN-20-1EP_4x4mm_P0.5mm_EP2.5x2.5mm
Y1: 16MHz; Oscillator_SMD_EuroQuartz_XO91-4Pin_7.0x5.0mm

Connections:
A_Button: R1.1, SW1.1, U1.6 (PA0)
Antenna: Antenna_nRF1.1 (Feed_point), C4.1, C5.1
B_Button: R2.1, SW2.1, U1.7 (PA1)
DC_Button: R8.1, SW8.1, U1.11 (PA5)
Digital_Out_Put: U1.27 (PB4), U3.5 (MISO)
GND: Antenna_nRF1.2 (GND), C1.2, C2.1, C3.2, C5.2, C6.1, C7.1, C8.2, C9.2, C10.2, C11.2, C12.2, C13.2, D3.1 (K), D4.1 (K), D5.1 (K), D6.1 (K), H1.1, H2.1, H3.1, H4.1, H5.1, H6.1, J1.2, R1.2, R2.2, R3.2, R4.2, R5.2, R6.2, R7.2, R8.2, R9.2, R10.2, R12.2, R13.2, R18.2, R19.2, U1.16 (VSS), U1.32 (VSS), U2.5 (GND), U2.6 (GND), U2.7 (GND), U2.8 (GND), U3.8 (VSS), U3.14 (VSS), U3.17 (VSS), U3.20 (VSS)
Glob_Alim: C1.1, C9.1, C10.1, D1.1 (K), D7.2 (A), SW1.2, SW2.2, SW3.2, SW4.2, SW5.2, SW6.2, SW7.2, SW8.2, SW9.2, SW10.2, SW12.2, SW13.2, U3.7 (VDD), U3.15 (VDD), U3.18 (VDD)
LC_Button: R6.1, SW6.1, U1.12 (PA6)
LED_Order: D2.2 (A), U1.22 (PA12)
Li-ion: C12.1, C13.1, J1.1, R14.1, R15.1, R16.1, R17.1, SW11.1
MOSI: U1.28 (PB5), U3.4 (MOSI)
NES/SNES_switcher: R19.1, SW13.1, U1.23 (PA13)
unnamed: C4.2, L1.2
unnamed: D1.2 (A), U2.3 (OUT)
unnamed: D2.1 (K), R18.1
unnamed: D3.2 (A), R15.2
unnamed: D4.2 (A), R16.2
unnamed: D5.2 (A), R14.2
unnamed: D6.2 (A), R17.2
unnamed: D7.1 (K), U1.1 (VDD), U1.5 (VDDA), U1.17 (VDD)
unnamed: C11.1, U2.4 (BP)
unnamed: SW11.2, U2.2 (IN)
unnamed: L1.1, L3.2, U3.12 (ANT1)
unnamed: L2.1, L3.1, U3.13 (ANT2)
unnamed: C8.1, U3.19 (DVDD)
unnamed: R12.1, U3.16 (IREF)
unnamed: C6.2, R11.1, U3.10 (XC1), Y1.2
unnamed: C7.2, R11.2, U3.9 (XC2), Y1.1
Order_Search: R13.1, SW12.1, U1.20 (PA10)
Pin_Clock: U1.26 (PB3), U3.3 (SCK)
RC_Button: R7.1, SW7.1, U1.13 (PA7)
RX/TX: U1.21 (PA11), U3.1 (CE)
Return_ANT: C2.2, C3.1, L2.2, U3.11 (VDD_PA)
SE_Button: R10.1, SW10.1, U1.19 (PA9)
ST_Button: R9.1, SW9.1, U1.18 (PA8)
UC_Button: R5.1, SW5.1, U1.10 (PA4)
X_Button: R3.1, SW3.1, U1.8 (PA2)
Y_Button: R4.1, SW4.1, U1.9 (PA3)

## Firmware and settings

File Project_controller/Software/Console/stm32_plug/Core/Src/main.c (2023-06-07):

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
/* Includes ------------------------------------------------------------------*/
#include "main.h"
/* USER CODE BEGIN Includes */
#include "NRF24.h"
/* USER CODE END Includes */

SPI_HandleTypeDef hspi1;

UART_HandleTypeDef huart2;
DMA_HandleTypeDef hdma_usart2_rx;

void SystemClock_Config(void);
static void MX_GPIO_Init(void);
static void MX_DMA_Init(void);
static void MX_SPI1_Init(void);
static void MX_USART2_UART_Init(void);
/**
  * @brief  The application entry point.
  * @retval int
  */
int main(void)
{
  /* MCU Configuration--------------------------------------------------------*/

  /* Reset of all peripherals, Initializes the Flash interface and the Systick. */
  HAL_Init();

  /* Configure the system clock */
  SystemClock_Config();

  /* Initialize all configured peripherals */
  MX_GPIO_Init();
  MX_DMA_Init();
  MX_SPI1_Init();
  MX_USART2_UART_Init();
  /* USER CODE BEGIN 2 */

  //Constants and variables declaration
  uint8_t Data_Latch_Pin = 4;
  uint8_t Data_Clock_Pin = 3;
  uint8_t Serial_Data_Pin = 5;
  GPIO_PinState Data_Latch = GPIO_PIN_RESET;
  GPIO_PinState Data_Clock = GPIO_PIN_RESET;
  GPIO_PinState Serial_Data = GPIO_PIN_RESET;

  //uint8_t Serial_Data_2_Pin = 6;
  //uint8_t IO_Bit=7;
  //uint8_t Pairing_Button = 4;

  uint8_t i = 0;

  //Pin (bit) number of the different buttons
  uint16_t B_Pin = 11;
  uint16_t Y_Pin = 9;
  uint16_t Select_Pin = 12;
  uint16_t Start_Pin = 4;
  uint16_t Cross_Up_Pin = 0;
  uint16_t Cross_Down_Pin = 1;
  uint16_t Cross_Left_Pin = 2;
  uint16_t Cross_Right_Pin = 3;
  uint16_t A_Pin = 10;
  uint16_t X_Pin = 8;
  uint16_t L_Pin = 13;
  uint16_t R_Pin = 5;

  uint8_t NRF_Data[2] = {0,0};
  uint16_t Button_Data = 0;
  uint8_t Bit_Number[16] = {B_Pin, Y_Pin, Select_Pin, Start_Pin, Cross_Up_Pin, Cross_Down_Pin, Cross_Left_Pin, Cross_Right_Pin, A_Pin, X_Pin, L_Pin, R_Pin, 0, 0, 0, 0};
  uint8_t step = 0;

  //NRF24 Initialization
  uint64_t RxpipeAddrs = 0x11223344AA;
  char myAckPayload[32] = "Ack by LM!";

  NRF24_begin(hspi1);
  NRF24_setAutoAck(true);
  NRF24_setChannel(52);
  NRF24_setPayloadSize(32);
  NRF24_openReadingPipe(1, RxpipeAddrs);
  NRF24_enableDynamicPayloads();
  NRF24_enableAckPayload();

  NRF24_startListening();

  HAL_Delay(1000);


  /* USER CODE END 2 */

  /* Infinite loop */
  /* USER CODE BEGIN WHILE */
  while (1)
  {

	  //Loop that detects the Data_Latch rising edge while updating the controller state
	  do {
		  //Wireless data reception
		  NRF24_read(NRF_Data, 2);
		  NRF24_writeAckPayload(1, myAckPayload, 2);
		  Button_Data = ((NRF_Data[1]<<8)||NRF_Data[0]);


		  Data_Latch = HAL_GPIO_ReadPin(GPIOB, Data_Latch_Pin);
	  }
	  while(Data_Latch == 0);


	  //When the rising edge is detected, transmission of the button states begins:
	  for(i=0;i<16; i++){

		  if ((Button_Data && Bit_Number[i]) == 0){
			  HAL_GPIO_WritePin(GPIOB, Serial_Data_Pin, GPIO_PIN_SET);
		  }
		  else{
			  HAL_GPIO_WritePin(GPIOB, Serial_Data_Pin, GPIO_PIN_RESET);
		  }

		  do{
			  Data_Clock = HAL_GPIO_ReadPin(GPIOB, Data_Clock_Pin);
		  }
		  while(Data_Clock == 1);
		  do{
			  Data_Clock = HAL_GPIO_ReadPin(GPIOB, Data_Clock_Pin);
		  }
		  while(Data_Clock == 0);
	  }
	  HAL_GPIO_WritePin(GPIOB, Serial_Data_Pin, GPIO_PIN_RESET);
	  /*
	  if(step<600){
		  if(Button_Data ==0){
	  	  		  Button_Data = 16;
	  	  	  }
	  	  else{
	  	  		  Button_Data = 0;
	  	  	  }
	  }
	  if((step>=600)){
		  if(Button_Data ==0){
			  Button_Data = 1024;
		  }
		  else{
			  Button_Data = 0;
		  	  }

	  }
	  step++;
	  HAL_UART_Transmit(&huart2,&step,1,HAL_MAX_DELAY);
	  */
    /* USER CODE END WHILE */

    /* USER CODE BEGIN 3 */
  }
  /* USER CODE END 3 */
}

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


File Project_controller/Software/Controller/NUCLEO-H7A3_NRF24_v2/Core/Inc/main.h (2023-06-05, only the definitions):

#define B1_Pin GPIO_PIN_13
#define B1_GPIO_Port GPIOC
#define OSC32_IN_Pin GPIO_PIN_14
#define OSC32_IN_GPIO_Port GPIOC
#define OSC32_OUT_Pin GPIO_PIN_15
#define OSC32_OUT_GPIO_Port GPIOC
#define USB_FS_PWR_EN_Pin GPIO_PIN_10
#define USB_FS_PWR_EN_GPIO_Port GPIOF
#define PH0_MCU_Pin GPIO_PIN_0
#define PH0_MCU_GPIO_Port GPIOH
#define PH1_MCU_Pin GPIO_PIN_1
#define PH1_MCU_GPIO_Port GPIOH
#define CSN_Pin_Pin GPIO_PIN_4
#define CSN_Pin_GPIO_Port GPIOA
#define CE_Pin_Pin GPIO_PIN_5
#define CE_Pin_GPIO_Port GPIOC
#define GREEN_LED_Pin GPIO_PIN_0
#define GREEN_LED_GPIO_Port GPIOB
#define LD3_Pin GPIO_PIN_14
#define LD3_GPIO_Port GPIOB
#define STLINK_RX_Pin GPIO_PIN_8
#define STLINK_RX_GPIO_Port GPIOD
#define STLINK_TX_Pin GPIO_PIN_9
#define STLINK_TX_GPIO_Port GPIOD
#define USB_FS_OVCR_Pin GPIO_PIN_7
#define USB_FS_OVCR_GPIO_Port GPIOG
#define USB_FS_VBUS_Pin GPIO_PIN_9
#define USB_FS_VBUS_GPIO_Port GPIOA
#define USB_FS_ID_Pin GPIO_PIN_10
#define USB_FS_ID_GPIO_Port GPIOA
#define USB_FS_N_Pin GPIO_PIN_11
#define USB_FS_N_GPIO_Port GPIOA
#define USB_FS_P_Pin GPIO_PIN_12
#define USB_FS_P_GPIO_Port GPIOA
#define LD2_Pin GPIO_PIN_1
#define LD2_GPIO_Port GPIOE

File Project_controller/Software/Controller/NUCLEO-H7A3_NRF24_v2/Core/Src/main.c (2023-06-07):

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
/* Includes ------------------------------------------------------------------*/
#include "main.h"
#include "spi.h"
#include "usart.h"
#include "usb_otg.h"
#include "gpio.h"

/* USER CODE BEGIN Includes */
#include "NRF24.h"
#include <stdio.h>
/* USER CODE END Includes */

/* USER CODE BEGIN PD */

// This is where every macro I use in the code is implemented
/*
 * UARTTXBUFFERSIZE is the size use for the TX buffer when communicating with uart
 * UARTRXBUFFERSIZE is the size use for the RX buffer when communicating with uart
 * LED2_PORT is use to control the port of the user LED 2
 * LED2_PIN is use to control the pin of the user LED 2
 *
 */
#define UARTTXBUFFERSIZE 32
#define UARTRXBUFFERSIZE 32
#define LED2_PORT GPIOE
#define LED2_PIN GPIO_PIN_1
/* USER CODE END PD */


/* USER CODE BEGIN PV */
// This is where the basic declaration are made
/*
 * uartTxBuffer is the buffer use for TX mode with uart communication
 * uartRxBuffer is the buffer use for RX mode with uart communication
 * huart3 is the uart configuration we are using
 * uartFlag is a flag the indicate whether or not a communication has been made from the computer to the board
 * mode indicate in which mode (between TX and RX) we are with SPI communication
 * msglu is use to indicate that a message has been receive with uart communication
 * RxPipeAddrs is the adress of the receiving pipe for the NRF24
 * myRxData is the buffer that will receive the data
 * myAckPayload is the payload that will indicate if the communication has really been made
 * TxpipeAddrs is the adress of the transmitting pipe for NRF24
 * myTxData is the text that will be send during test phase
 * AckPayload is the buffer that will be use for collecting the data of the ACK payload
 *
 */
extern char uartTxBuffer[UARTTXBUFFERSIZE];
extern char uartRxBuffer[UARTRXBUFFERSIZE];
extern UART_HandleTypeDef huart3;
extern uint8_t uartFlag;
int mode ;

char* msglu = "\r\nMessage recu !\r\n";

//RX mode
uint64_t RxpipeAddrs = 0x11223344AA;
char myRxData[50];
char myAckPayload[32] = "Ack by STM32H7!";

//TX mode
uint64_t TxpipeAddrs = 0x11223344AA;
char myTxData[32] = "Hello World!";
char AckPayload[32];


/* USER CODE END PV */

void SystemClock_Config(void);
void PeriphCommonClock_Config(void);
/**
 * @brief  The application entry point.
 * @retval int
 */
int main(void)
{
	/* MCU Configuration--------------------------------------------------------*/

	/* Reset of all peripherals, Initializes the Flash interface and the Systick. */
	HAL_Init();

	/* Configure the system clock */
	SystemClock_Config();

	/* Configure the peripherals common clocks */
	PeriphCommonClock_Config();

	/* Initialize all configured peripherals */
	MX_GPIO_Init();
	MX_USART3_UART_Init();
	MX_USB_OTG_HS_USB_Init();
	MX_SPI1_Init();
	/* USER CODE BEGIN 2 */
	HAL_UART_Transmit(&huart3, (uint8_t*) "Booting...\r\n",12,100);


	/*
	 *
	 * This is where the configuration of the NRF24 is made, the only thing needed to change from TX to RX is to comment the instruction for TX or RX
	 * depending on which mode you want to use.
	 *
	 */
	// TX mode
	mode = 0;

	//RX mode
	//mode = 1;



	switch(mode){
	case 0:										// Configuration for TX mode
		NRF24_begin(hspi1);						// Initialise the NRF24 with default value and link to hspi1
		nrf24_DebugUART_Init(huart3);			// Use to make sure huart3 is connected

		printRadioSettings();					// A first print of the setting of the NRF24

		NRF24_stopListening();					// This is to disable the NRF24 while we continue the setup
		NRF24_openWritingPipe(TxpipeAddrs);		// This setup the TX pipe
		NRF24_setAutoAck(true);					// Configure the auto acknowledge
		NRF24_setChannel(52);					// Confire the channel where the NRF24 will be communicating
		NRF24_setPayloadSize(32);				// Define the payload size

		NRF24_enableDynamicPayloads();			// Enable the Dynamic payload (must be enable for ACK mode)
		NRF24_enableAckPayload();				// Enable the ACK payload (must be enable for ACK mode)
		break;
	case 1:										// Configuration for RX mode
		NRF24_begin(hspi1);						// Initialise the NRF24 with default value and link to hspi1
		nrf24_DebugUART_Init(huart3);			// Use to make sure huart3 is connected

		printRadioSettings();					// A first print of the setting of the NRF24

		NRF24_setAutoAck(true);					// Configure the auto acknowledge
		NRF24_setChannel(52);					// Configure the channel where the NRF24 will be communicating
		NRF24_setPayloadSize(32);				// Define the payload size
		NRF24_openReadingPipe(1, RxpipeAddrs);	// This setup the RX pipe
		NRF24_enableDynamicPayloads();			// Enable the Dynamic payload (must be enable for ACK mode)
		NRF24_enableAckPayload();				// Enable the ACK payload (must be enable for ACK mode)

		NRF24_startListening();					// Enable the listening of the NRF24
		break;
	}


	printRadioSettings();						// Print the final configuration of the NRF24

	/* USER CODE END 2 */

	/* Infinite loop */
	/* USER CODE BEGIN WHILE */
	while (1){
		/* USER CODE END WHILE */

		/* USER CODE BEGIN 3 */
		/*
		 *
		 * The first part is set to test the uart communication
		 * at first, it was suppose to be: pc -> uart -> board 1 -> spi -> NRF24 TX -> NRF24 RX -> spi -> board 2 -> uart -> pc
		 * Everytime a g is entered, it will print the current memory of every register of the NRF24
		 * In other cases, it will just make the second user LED flicker.
		 *
		 */
		if(uartFlag == 1){
			switch(uartRxBuffer[0]){
			case 'g' :
				HAL_UART_Transmit(&huart3,(uint8_t*) "et informations for nrf24\r\n",27,100);
				void NRF24_ShowMemory() ;
				break;
			default :
				HAL_GPIO_TogglePin(LED2_PORT,  LED2_PIN) ;
				HAL_UART_Transmit(&huart3, (uint8_t*) msglu, 18, 100) ;
				HAL_GPIO_TogglePin(LED2_PORT,  LED2_PIN) ;
				break;
			}
			uartFlag = 0 ;
		}


		/*
		 *
		 * This is the code for the NRF24.
		 * The case 0 is for the transmission
		 * The NRF24_read is to confirm that the AckPayload has been filled.
		 * The rest of the code is to transmit to the uart (this is mainly for test purpose)
		 *
		 * The case 1 is for the receive
		 * It first check if there is data available then will put it in the RxData buffer.
		 * The rest is also to transmit to the uart for test purpose
		 *
		 */
		switch(mode){
		case 0:
			if(NRF24_write(myTxData, 32)){
				NRF24_read(AckPayload, 32);
				HAL_UART_Transmit(&huart3, (uint8_t *)"Transmitted Successfully\r\n", strlen("Transmitted Successfully\r\n"), 10);

				char myDataack[80];
				sprintf(myDataack, "AckPayload:  %s \r\n", AckPayload);
				HAL_UART_Transmit(&huart3, (uint8_t *)myDataack, strlen(myDataack), 10);
			}
			break;
		case 1:
			if(NRF24_available()){
				NRF24_read(myRxData, 32);
				NRF24_writeAckPayload(1, myAckPayload, 32);
				myRxData[32] = '\r'; myRxData[32+1] = '\n';
				HAL_UART_Transmit(&huart3, (uint8_t *)myRxData, 32+2, 10);
			}
			break ;
		}

		HAL_Delay(1000);


	}
	/* USER CODE END 3 */
}

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


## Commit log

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2023-04-15 Add the two kicad schematic/PCB layer of the controller receptor in the hardware file, and a README about it.
    [RecepteurSNES-ModuleNRF24ext.kicad_pcb, RecepteurSNES-ModuleNRF24ext.kicad_sch, RecepteurSNES-ModuleNRF24inc.kicad_pcb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]
2023-04-15 Updated Schematic & PCB / Work in progress (Tracks & Netclasses)
    [ProjetSNES2023ENSEA.kicad_pcb, ProjetSNES2023ENSEA.kicad_sch, [Backup] ProjetSNES2023ENSEA copy.kicad_pcb]
2023-04-16 Updated Schematic & PCB
    [ProjetSNES2023ENSEA.kicad_pcb, ProjetSNES2023ENSEA.kicad_sch]
2023-04-16 Updated Schematic & PCB (Bug Fixes)
2023-04-16 Updated Schematic & PCB (New netclasses / Antenna still need to be connected)
    [ProjetSNES2023ENSEA.kicad_pcb, ProjetSNES2023ENSEA.kicad_sch]
2023-04-16 Updated Schematic & PCB (Netclass, Power Flag, Library, Antenna)
    [ProjetSNES2023ENSEA.kicad_pcb, ProjetSNES2023ENSEA.kicad_sch]
2023-04-16 Updated Schematic & PCB (Netclass, Power Flag, Library, Antenna) 2
    [ProjetSNES2023ENSEA.kicad_pcb, ProjetSNES2023ENSEA.kicad_sch]
2023-04-16 Updated Schematic & PCB (Text / Miscellaneous / Antenna WIP)
    [ProjetSNES2023ENSEA.kicad_pcb]
2023-04-16 Correction on the PCB layer of the nRF24ext model
2023-04-16 Correction of the last commit
    [RecepteurSNES-ModuleNRF24ext.kicad_pcb, RecepteurSNES-ModuleNRF24ext.kicad_sch]
2023-04-16 Update of the readme and the architecture of the files
    [Projet_manette_proto.csv, Projet_manette_proto.kicad_pcb, Projet_manette_proto.kicad_sch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]
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2023-04-16 Updated NRF24L01 (Exclude & Include) Kicad projects to revision 2.0
    [SNES_Controller_NRF24L01_Exclude.kicad_pcb, SNES_Controller_NRF24L01_Exclude.kicad_sch, SNES_Controller_NRF24L01_Include.kicad_pcb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]
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2023-04-17 controler without nRF 24 homemade
    [Projet_manette_modu_Exter.kicad_pcb, Projet_manette_modu_Exter.kicad_sch]
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2023-04-17 Corrective changes on the Plug_NRF24L01_Exclude KiCad
    [Plug_NRF24L01_Exclude.kicad_pcb, Plug_NRF24L01_Exclude.kicad_sch]
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2023-04-17 Thanks M.Papazoglou,more led, more Software problem
    [Controller_NRF24L01_Include.kicad_pcb, Controller_NRF24L01_Include.kicad_sch, DIODE_sch.kicad_sch]
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2023-04-18 Updated Plug_NRF24L01_Include Schematic & Include (Added new components and modified footprints). Fixed some errors on NRF24L01_Exclude.
    [Plug_NRF24L01_Exclude.kicad_sch, Plug_NRF24L01_Include.kicad_pcb, Plug_NRF24L01_Include.kicad_sch]
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2023-04-18 Updated PCB (Grouping and Tracks)
    [Plug_NRF24L01_Include.kicad_pcb, Plug_NRF24L01_Include.kicad_sch]
2023-04-18 New controler versions, and not the last
    [Controller_NRF24L01_Include.kicad_pcb, Controller_NRF24L01_Include.kicad_sch, DIODE_sch.kicad_sch]
2023-04-19 Updated Plug_NRF24L01_Include. Schematic (Pins assignment / Appairing Button). PCB (Finalized routing / Antenna not working).
    [Plug_NRF24L01_Include.kicad_pcb, Plug_NRF24L01_Include.kicad_sch]
2023-04-19 Updated Plug_NRF24L01_Include (Version 1.0) - Schematic (New pins assignment / New button / New SWD Connector) - PCB (Finalized Routing / Antenna not working)
2023-04-19 Updated Plug_NRF24L01_Exclude (Version 1.0) - Schematic (New pins assignment / New buttons) - PCB (Completed Routing V1)
    [Plug_NRF24L01_Exclude.kicad_pcb, Plug_NRF24L01_Exclude.kicad_sch, Plug_NRF24L01_Include.kicad_sch]
2023-04-23 New New controler vers
    [Controller_NRF24L01_Include.kicad_pcb, Controller_NRF24L01_Include.kicad_sch, DIODE_sch.kicad_sch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]
2023-04-27 Updated Plug_NRF24L01_Include (V1.1) - PCB
    [Plug_NRF24L01_Include.kicad_pcb, Plug_NRF24L01_Include.kicad_sch]
2023-04-27 Updated Plug_NRF24L01_Include (V1.1a) - Fixes (Text)
    [Plug_NRF24L01_Include.kicad_pcb]
2023-04-28 Updated Plug_NRF24L01_Include (V1.1b) - Fixes (Keepout area)
    [Plug_NRF24L01_Include.kicad_pcb]
2023-04-28 Updated Plug_NRF24L01_Exclude (V1.1) - PCB (Routing) / Schematic (Pins assignment)
    [Plug_NRF24L01_Exclude.kicad_pcb, Plug_NRF24L01_Exclude.kicad_sch]
2023-04-28 Updated Plug_NRF24L01 (Text, ruler, images)
    [Plug_NRF24L01_Exclude.kicad_pcb, Plug_NRF24L01_Exclude.kicad_sch, Plug_NRF24L01_Include.kicad_pcb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]
2023-04-30 New New New version of the controler include, we hope that will be the last
    [Controller_NRF24L01_Include.kicad_pcb]
2023-05-03 And a new version of the controler
    [Controller_NRF24L01_Include.kicad_pcb, Controller_NRF24L01_Include.kicad_sch]
2023-05-03 Maybe the final version
    [Controler_NRF24L01_Exclude.kicad_sch, Controller_NRF24L01_Include.kicad_pcb, Controller_NRF24L01_Include.kicad_sch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]
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2023-05-04 Change the name of a folder that was missnamed
    [Base de la manette.stl, Haut de la manette v5.stl]
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2023-05-04 update of the folder 'controler_NRF24L01_Exclude' -> replace by the correction given
    [Controler_NRF24L01_Exclude.kicad_pcb, Controler_NRF24L01_Exclude.kicad_sch, Diode.kicad_sch]
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2023-05-09 Change of the nRF24 connector on the PCB (1mm -> 2.54mm)
    [Plug_NRF24L01_Exclude.kicad_sch]
2023-05-09 Updated Plug_NRF24L01_Exclude (V2.0) - Schematic (NRF24 Connector) - PCB (Capacitor)
    [Plug_NRF24L01_Exclude.kicad_pcb, Plug_NRF24L01_Exclude.kicad_sch]
2023-05-09 Added a capacitor of 10u for the power of the STM32 on the schematics of the plugs
    [Plug_NRF24L01_Exclude.kicad_sch, Plug_NRF24L01_Include.kicad_sch]
2023-05-09 Updated Plug_NRF24L01_Exclude (V2.1) - Schematic & PCB (Added 10μ Capacitor)
    [Plug_NRF24L01_Exclude.kicad_pcb, Plug_NRF24L01_Exclude.kicad_sch]
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2023-05-12 Updated Plug_NRF24L01_Include (V2.1) - Schematic & PCB & Image
    [Plug_NRF24L01_Include.kicad_pcb, Plug_NRF24L01_Include.kicad_sch]
2023-05-12 Update Plug_NRF24L01_Exclude (V2.1b) - Schematic & Image (Bug Fix)
    [Plug_NRF24L01_Exclude.kicad_sch]
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2023-05-15 nrf24 module is now always in RX/TX mode during operation, module switches to this mode in the initialization. Fixed var name 'register' being a data type.
    [nrf24l01custom.c]
2023-05-15 fixed missing data type in receive and transmit functions
    [nrf24l01custom.c]
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2023-05-15 Correction in the code, add of a LED test to see if it's working (only the UART is working currently, SPI not yet implemented)
    [main.c]
2023-05-15 Correction of the correction
    [NRF24.c, usart.c]
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2023-05-16 Add a library for NRF24 inside the projet, currently the library only handel Transmit and seems to be have an unknown issue somewhere. Still working on it
    [NRF24.c, NRF24.h, NUCLEO-H7A3_NRF24_v2.ioc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]
2023-05-16 Very small correction in the library, CS pin is not supposed to be modified inside the init function. The error is still not found but is inside the init (maybe an error in the adresses or inside the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
    [NRF24.c]
2023-05-16 Kicad fixed
    [Controler_NRF24L01_Exclude.kicad_sch, Controler_NRF24L01_Exclude_v2.kicad_pcb, Controler_NRF24L01_Exclude_v2.kicad_sch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]
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2023-05-16 Add the RX code, error has been found: the programm seem unable to understand that data has been send (or is unable to sned data), still working on the issue
    [NRF24.c, NRF24.h, main.c]
2023-05-16 Correction of one of the error the code add. Now the transmission seems to work but there is a problem with the receive: the FIFO is always empy and no data can be collected from it (so maybe the tra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
    [NRF24.c, NRF24.h, NUCLEO-H7A3_NRF24_v2.ioc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]
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2023-05-22 Update v2.2a - Plug_NRF24L01_Exclude (SWD_Connector, GND Vias) - Controller_NRF24L01_Exclude (Schematic) - Cleaned Folders
    [Controler_NRF24L01_Exclude.kicad_pcb, Controler_NRF24L01_Exclude.kicad_sch, Controler_NRF24L01_Exclude_v2.kicad_pcb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]
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2023-05-22 Upadte Plug_NRF24L01_Exclude v3.0b (Completed routing / Added images)
    [Plug_NRF24L01_Exclude.kicad_pcb, Plug_NRF24L01_Exclude.kicad_sch]
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2023-05-23 Update Plug_NRF24L01_Exclude v3.0c (Commit fixes)
    [Plug_NRF24L01_Exclude.kicad_pcb, Plug_NRF24L01_Exclude.kicad_sch]
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2023-05-30 fix pcb v3
    [Controler_NRF24L01_Exclude_v3.kicad_pcb]
2023-05-30 added the (almost) completed stm32 projects. The only part missing is the wireless communication
    [functions.c, main.c, main.h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]
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2023-05-30 Update Plug_NRF24L01_Exclude v4.0a (Schematic Fixes / New PCB Routing) - Added new images
    [Plug_NRF24L01_Exclude.kicad_pcb, Plug_NRF24L01_Exclude.kicad_sch]
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2023-06-05 Final correction of the nrf24 library. It seems to be working know even so their must be a problem (I hope due to the cable)
    [NRF24.c, NRF24.h, NUCLEO-H7A3_NRF24_v2.ioc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]
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2023-06-06 fixed declaration errors and typos
    [NRF24.c, NRF24.h, functions.c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]
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2023-06-24 Update of the repository, prepare it for the second part of the project: the consol itsefl
    [Base de la manette v22.stl, Base de la manette v26.stl, Base de la manette v9.stl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]
2023-06-24 Update of the repository, prepare it for the second part of the project: the consol itself
    [Base de la manette v22.stl, Base de la manette v26.stl, Base de la manette v9.stl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]
2023-09-19 Add the folders to start working on the project. Create the FPGA project with DE1-SoC board. txt files were added so the folders would be seen by the other collaborators. Typos have been corrected.
    [c5_pin_model_dump.txt]
2023-10-03 Deletion of the console project: we will create a new repository due to the fact we change from SNES to NES
    [c5_pin_model_dump.txt]

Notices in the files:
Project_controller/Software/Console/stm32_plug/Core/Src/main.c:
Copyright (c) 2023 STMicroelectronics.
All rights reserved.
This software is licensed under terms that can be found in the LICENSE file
